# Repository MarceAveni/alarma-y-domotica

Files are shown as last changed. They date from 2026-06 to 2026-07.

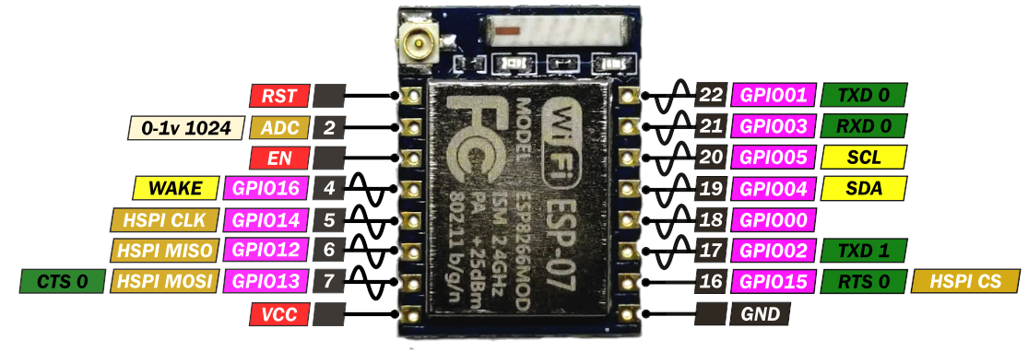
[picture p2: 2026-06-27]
Diseño y Hardware/Desarrollo de Hardware/Frente - ESP8266/Documentacion/ESP07-PinOut_solo.png

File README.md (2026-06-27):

# Alarma y Domótica del Hogar

Este repositorio unifica el código fuente de los firmwares, modelos 3D, esquemas de hardware y documentación general de los sistemas de automatización y seguridad instalados en el hogar.

## 🚀 Versión 1.0 - Versión Inicial Estable
Esta es la primera versión completada, probada y en funcionamiento del sistema integrado.

---

## 📂 Estructura del Repositorio

*   **`Control integrado - Frente/`**: Firmware para el módulo ESP8266 que controla la seguridad del frente, sensores de movimiento PIR, sirena, reflectores y luces de vereda.
*   **`Control integrado - Patio/`**: Firmware para el módulo ESP32 que controla la temperatura de la piscina (pileta), colectores térmicos solares, nivel de agua y luces de la galería/patio.
*   **`Diseño y Hardware/`**:
    *   `Modelos 3D y Planos/`: Planos CAD (.dwg) y archivos STL listos para imprimir en 3D del gabinete central, gabinete frente y soportes generales.
    *   `Desarrollo de Hardware/`: Documentación técnica (pinouts) y directorios reservados para futuras revisiones de placas.

---

## 📡 Arquitectura de Comunicaciones (MQTT)

Ambas placas están conectadas a la red WiFi local y se comunican a través de un broker MQTT público (`broker.emqx.io`).

*   **Topic de Comandos (Escuchan ambos):** `BALH142N1788/Aveni793`
    *   Ambos dispositivos procesan mensajes JSON en este canal y extraen solo las variables de control que les corresponden.
*   **Topic de Telemetría Frente (ESP8266):** `BALH142N1788/Frente`
*   **Topic de Telemetría Patio (ESP32):** `BALH142N1788/Patio`

---

## 🛠️ Herramientas de Desarrollo

*   **Firmware:** [PlatformIO](https://platformio.org/) integrado en VS Code.
*   **Carga de Firmware:** Soporta programación inalámbrica **OTA** (Over The Air) localmente en ambos módulos.
*   **Espacio de Trabajo de VS Code:** Abrir el archivo `Control ESP32 - Patio.code-workspace` en la raíz para cargar ambos proyectos de firmware simultáneamente.

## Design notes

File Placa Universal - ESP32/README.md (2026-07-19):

# Placa Universal ESP32-S3 (Motherboard / Shield)

Este directorio contiene todo el diseño de hardware, modelos 3D y firmwares unificados bajo la arquitectura de la placa universal basada en el **ESP32-S3**.

## 📂 Estructura de Directorios

*   **`Hardware/`**: Archivos de diseño electrónico y documentación.
    *   `Proyecto PCB/`: Carpeta del proyecto de diseño electrónico (Altium/KiCad) que aloja los archivos de diseño y fabricación.
    *   `Diseño/`: Documentación del diseño (requerimientos, recomendaciones y pinouts) y hojas de datos de los componentes.
*   **`Modelos 3D/`**: Diseños de gabinetes protectores y soportes impresos en 3D específicos para esta placa universal.
*   **`Firmware/`**: Proyectos PlatformIO individuales para cada nodo, compartiendo código común.
    *   `Librerias_Compartidas/`: Librerías y clases C++ comunes para WiFi, MQTT, OTA, gestión de tiempo y programaciones horarias.
    *   `Frente_S3/`: Firmware específico para el nodo del Frente (Sirena, reflectores, PIRs, etc.).
    *   `Patio_S3/`: Firmware específico para el nodo del Patio/Galería (Colectores solares, piscina, nivel de agua, etc.).
    *   `Simple_S3/`: Firmware específico para el nodo Simple (reemplazo del ESP-01 para reflectores auxiliares).

## 🛠️ Compartición de Código (PlatformIO)

Para reutilizar lógica común de red y MQTT sin duplicar código, los proyectos individuales de PlatformIO configuran la directiva `lib_extra_dirs` apuntando a `Librerias_Compartidas`.

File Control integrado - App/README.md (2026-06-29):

# Propuesta de Arquitectura y Diseño de la Aplicación Móvil
## Sistema Control Integrado - Nuestro Hogar (Alarma y Domótica)

Este documento detalla la estructura tentativa, diseño estético y mapeo de variables para la nueva aplicación móvil del sistema de domótica y seguridad del hogar. Está diseñada para ser **completa, intuitiva, escalable y con un estilo visual moderno**, adaptándose tanto a los firmwares actuales (Frente y Patio) como a futuros nodos de hardware.

---

## 1. Arquitectura de Integración y Escalabilidad

La comunicación de la aplicación móvil se realiza a través de un **Broker MQTT** (actualmente `broker.emqx.io`). La App se suscribe a los temas de estado publicados por los diferentes nodos del hogar y publica comandos en los temas correspondientes para actuar sobre el hardware.

```mermaid
graph TD
    %% Estilos de nodos
    classDef app fill:#4E73DF,stroke:#fff,stroke-width:2px,color:#fff;
    classDef broker fill:#1CC88A,stroke:#fff,stroke-width:2px,color:#fff;
    classDef nodeF fill:#36B9CC,stroke:#fff,stroke-width:2px,color:#fff;
    classDef nodeP fill:#F6C23E,stroke:#fff,stroke-width:2px,color:#fff;
    classDef nodeFut fill:#858796,stroke:#fff,stroke-width:1px,color:#fff,stroke-dasharray: 5 5;

    App[App Móvil <br>Android - Kotlin / Jetpack Compose] <--> Broker[Broker MQTT <br>broker.emqx.io]
    Broker <--> ESP_Frente[ESP8266 <br>Control Frente]
    Broker <--> ESP_Patio[ESP32 <br>Control Patio]
    Broker -.-> ESP_Futuros[ESP32 / ESP8266 <br>Nodos Futuros]

    subgraph ESP_Frente [Control Frente ESP8266-07]
        DHT11_F[DHT11 Temp & Hum]
        PIRs[Sensores PIR1 & PIR2]
        LDR_F[Fotoresistencia]
        Sirena_F[Actuador Sirena]
        Reflectores_F[Reflectores Vereda/Entrada]
        LuzVereda_F[Luz de Vereda]
        Camaras_F[Alimentación Cámaras]
    end

    subgraph ESP_Patio [Control Patio ESP32]
        DHT22_P[DHT22 Temp & Hum]
        DS18B20[DS18B20 Pileta & Colector]
        Nivel_P[Sensor de Nivel de Agua]
        LDR_P[LDR Luz Patio]
        BombaPileta[Bomba Pileta]
        BombaCisterna[Bomba Cisterna]
        BombaTanque[Bomba Tanque]
        LucesPatio[Reflectores / Luz Pileta / Galería]
        Auxiliares[Salidas Aux1 & Aux2]
    end

    class App app;
    class Broker broker;
    class ESP_Frente nodeF;
    class ESP_Patio nodeP;
    class ESP_Futuros nodeFut;
```

### Principio de Escalabilidad (Futuro Hardware)
Para asegurar que se puedan agregar sensores y actuadores en el futuro sin rediseñar la App desde cero:
1. **Estructura Temática MQTT Jerárquica**: Los nuevos nodos utilizarán la estructura `NuestroHogar/[Nombre_Nodo]/Estado` para publicar telemetría en JSON y `NuestroHogar/[Nombre_Nodo]/Comando` para recibir configuraciones.
2. **Interfaz de Carga Dinámica / Modular**: La UI de la App se construirá sobre la base de tarjetas o módulos reutilizables. Si se detecta un nuevo nodo en la red MQTT, la App podrá autogenerar una sección básica o permitir activarla desde los ajustes.

---

## 2. Mapa de Navegación: Pestañas y Sectores

Se propone una interfaz con una **barra de navegación inferior (Bottom Navigation Bar)** moderna de 5 pestañas principales. Cada una de ellas agrupa un sector lógico del hogar.

### Pestaña 1: Inicio (Dashboard)
Es la pantalla de bienvenida y control rápido. Diseñada para dar información crítica de un vistazo y permitir acciones inmediatas.
*   **Estado de Conexión**: Indicador visual arriba (MQTT Conectado/Desconectado, retardo de ping).
*   **Botón de Pánico Sirena**: Botón rojo central vibrante con efecto de brillo ("Glow") y confirmación de doble toque para encender/apagar la sirena inmediatamente en caso de emergencia.
*   **Resumen Climatológico**: Tarjeta con la temperatura y humedad exterior promedio (Frente + Patio).
*   **Resumen Pileta**: Muestra rápida de la temperatura actual de la pileta y si el sistema solar está en funcionamiento.
*   **Alertas Activas**: Banner dinámico si hay alarmas de movimiento recientes, nivel de cisterna bajo, o si alguna bomba lleva funcionando más de lo normal.

### Pestaña 2: Climatización (Pileta)
Sector especializado en el control del climatizador solar de la pileta y las bombas.
*   **Dial de Control Termostato**: Control circular interactivo y táctil para setear `tempSet` (temperatura de consigna de la pileta).
*   **Monitoreo Térmico**:
    *   `tempPileta` (Temperatura actual del agua).
    *   `tempColector` (Temperatura en colectores solares del techo).
    *   `Diferencial de Temperatura` (`tempColector - tempPileta` con indicación visual de transferencia de calor).
*   **Modo de Bomba Pileta**: Selector de tres estados (Apagado / Encendido / Automático) utilizando controles deslizantes o botones segmentados de diseño premium.
*   **Interruptor de Intercambio Solar**: Switch de activación para la lógica automática diferencial (`IntercambioST`).
*   **Diagnóstico de Bomba**:
    *   Estado real de funcionamiento (`bombaPiletaST`).
    *   Tiempo actual de encendido continuo y tiempo acumulado en el día.
    *   Alertas de seguridad (si está bloqueada por `minOffTime` o apagada por `maxOnTime`).

### Pestaña 3: Iluminación y Servicios (Domótica)
Sector dedicado al control de luces, bombas de agua y relés auxiliares.
*   **Sección Luces**: Tarjetas dinámicas con micro-animaciones (cambio de tonalidad y gradiente cuando se encienden).
    *   *Frente*: Reflectores (Apagado/Encendido/Auto), Luz de Vereda (Apagado/Encendido/Auto).
    *   *Patio*: Reflectores Patio (Apagado/Encendido/Auto), Luces Pileta (Apagado/Encendido/Auto), Luz Galería (Apagado/Encendido/Auto), Luz Galería Borde (Apagado/Encendido/Auto).
*   **Sección Agua (Pumps)**:
    *   **Nivel de Cisterna**: Gráfico de barra vertical con degradado azul que muestra si el sensor capacitivo detecta agua (`nivelAguaST`).
    *   **Bomba Cisterna**: Control segmentado (Apagado / Encendido / Auto).
    *   **Bomba Tanque**: Control segmentado (Apagado / Encendido / Auto).
*   **Sección Auxiliares**:
    *   Interruptores rápidos para `Aux1` y `Aux2`. Permite personalizar el nombre desde la interfaz (ej. "Riego", "Cascada Pileta").

### Pestaña 4: Seguridad (Alarma)
Control completo de la seguridad perimetral de la casa.
*   **Armado de Alarma**: Estado de armado general de la casa (permite integrar lógica de armado ausente/presente en el futuro).
*   **Alimentación de Cámaras**: Interruptor directo para apagar o encender (resetear) las cámaras de seguridad (`CamarasEn`).
*   **Configuración de Sirena**: Modo de Sirena general (Apagada / Automática).
*   **Estado de Sensores**:
    *   Visualización de detección en tiempo real para `PIR1` y `PIR2`.
    *   Interruptor para deshabilitar individualmente cada sensor (`PIR1En`, `PIR2En`) si alguno empieza a fallar o dar falsos positivos.
*   **Historial de Eventos (Log de Movimientos)**:
    *   Registro temporal de detecciones de movimiento.
    *   Filtro por día (con selector de fecha nativo en calendario) para auditoría de movimientos históricos.

### Pestaña 5: Configuración Avanzada (Variables)
Sector protegido para calibrar el comportamiento de los algoritmos de las placas ESP.
*   **Parámetros de Pileta**:
    *   Entradas numéricas para delta de encendido (`tempDif_on`) y delta de apagado (`tempDif_off`).
    *   Ajuste de tiempos de protección de bomba en minutos (`minOnTime`, `minOffTime`, `maxOnTime`).
*   **Ajustes de Luz y Noche**:
    *   Ajuste del umbral `ValorNoche` del conversor analógico-digital (ADC) para clasificar cuándo es de noche.
    *   Ajuste de histéresis (`histeresisLuz`).
*   **Configuración del Sistema**:
    *   Intervalo de telemetría en segundos (`intervalData`).
    *   Parámetros del Broker MQTT (Host, Port, User, Pass).
    *   **Diagnóstico de Hardware**: Mapeo de WiFi (señal RSSI en dBm de Frente y Patio), direcciones IP asignadas, tiempo de actividad (uptime) y opción de iniciar actualización de firmware OTA de forma inalámbrica.

---

## 3. Guía de Diseño Estético y Experiencia de Usuario (UX/UI)

Para lograr una interfaz premium, intuitiva y moderna (diseño "WOW"), se propone seguir las siguientes pautas visuales:

1.  **Gama de Colores e Identidad Visual**:
    *   **Tema Oscuro por Defecto**: Fondo en gris muy oscuro (`#121214` o `#0F0F12`) con tarjetas en gris grafito (`#1E1E24`) y bordes muy sutiles (`#2D2D35`). Esto ahorra batería (pantallas OLED/AMOLED) y da un aspecto tecnológico de alta gama.
    *   **Acentos de Color por Categoría**:
        *   *Domótica/Climatización*: Azul eléctrico (`#00D4FF` o `#007BFF`) y turquesa.
        *   *Iluminación*: Amarillo cálido / Ámbar (`#FFB300` o `#FF8F00`) simulando la calidez de los filamentos.
        *   *Seguridad*: Rojo vivo (`#FF3B30`) y Naranja (`#FF9500`).
        *   *Estado OK*: Verde esmeralda (`#34C759`).
2.  **Morfología (Glassmorphism)**:
    *   Uso de tarjetas translúcidas con desenfoque de fondo ("background blur") y bordes degradados muy finos que simulan vidrio sobre un fondo con sutiles orbes de color desenfocados.
    *   Esquinas redondeadas suaves (entre 12dp y 16dp) para una estética moderna y amigable.
3.  **Controles de Interacción e Iconografía**:
    *   Uso de iconos vectoriales limpios y de trazo fino (estilo Outlined de Material Design 3).
    *   Diales táctiles circulares y fluidos para variables analógicas (temperatura setpoint).
    *   Feedback háptico (vibración suave) al interactuar con interruptores y botones clave (como el botón de pánico).

---

## 4. Estructura de Datos y Comunicación MQTT

A continuación, se detalla la matriz de comunicación de la aplicación con los dos sistemas de hardware actuales:

### Canalización de Mensajería: Control Frente (ESP8266)

| Variable / Control | Dirección | Tema (Topic) MQTT | Formato de Payload / Valores |
| :--- | :--- | :--- | :--- |
| **Temperatura Frente** | Recibe de ESP | `Ambiente/Temp` | Texto: `"Temperatura: [Valor] "` (ej. `"Temperatura: 25 "`) |
| **Humedad Frente** | Recibe de ESP | `Ambiente/Hum` | Texto: `"Humedad: [Valor] "` (ej. `"Humedad: 60 "`) |
| **Luz Frente** | Recibe de ESP | `Ambiente/Luz` | Texto: `"Es de [día/noche]: [Valor]"` |
| **Sensor PIR 1** | Recibe de ESP | `Movimiento/PIR1` | Texto: `"Movimiento Detectado!!!"` |
| **Sensor PIR 2** | Recibe de ESP | `Movimiento/PIR2` | Texto: `"Movimiento Detectado!!!"` |
| **Contador de Movimientos**| Recibe de ESP | `Movimiento/PIRc` | Texto: `"Cant. de movimientos detectados: [Valor] "` |
| **Reflectores Frente** | Envía a ESP | `Iluminacion/Reflectores`| Entero: `0` (Apagado), `1` (Encendido) *(Se propone expandir a `2` Auto)* |
| **Luz Vereda** | Envía a ESP | `Iluminacion/Vereda` | Entero: `0` (Apagado), `1` (Encendido) *(Se propone expandir a `2` Auto)* |
| **Sirena** | Envía a ESP | `Alarma/Sirena` | Entero: `0` (Apagado), `1` (Encendido) |
| **Cámaras** | Envía a ESP | `Alarma/Camaras` | Entero: `0` (Apagado), `1` (Encendido) |

### Canalización de Mensajería: Control Patio (ESP32)

El ESP32 del patio utiliza un formato JSON estructurado, lo que optimiza el tráfico de datos y simplifica la expansión de variables.

*   **Tema de Publicación (Telemetría)**: `BALH142N1788/Patio`
*   **Tema de Suscripción (Comandos)**: `BALH142N1788/Aveni793`

#### Estructura del JSON de Telemetría (Publicado por ESP32):
```json
{
  "tempPileta": 24.5,
  "tempColector": 28.2,
  "bombaPiletaST": false,
  "bombaPiletaConf": 2,
  "tempSet": 30.0,
  "tempDif_on": 5.0,
  "tempDif_off": 2.0,
  "minOnTime": 60000,
  "minOffTime": 300000,
  "maxOnTime": 900000,
  "bombaCisternaST": false,
  "bombaCisternaConf": 2,
  "bombaTanqueST": false,
  "bombaTanqueConf": 2,
  "reflectoresST": false,
  "reflectoresConf": 2,
  "luzPiletaST": false,
  "luzPiletaConf": 2,
  "luzGaleriaST": false,
  "luzGaleriaConf": 2,
  "luzGaleriaBordeST": false,
  "luzGaleriaBordeConf": 2,
  "luzAmbiente": 450,
  "nivelAgua": true,
  "tempTecho": 22.1,
  "humTecho": 55.0,
  "IntercambioST": true,
  "tempPiletaCrudo": 24.53,
  "tempColectorCrudo": 28.18
}
```

#### Estructura del JSON de Comandos (Enviado por la App):
La aplicación puede enviar un JSON parcial conteniendo únicamente las llaves que desea modificar.
```json
{
  "tempSet": 29.5,
  "bombaPiletaConf": 2,
  "reflectoresConf": 1,
  "luzPiletaConf": 0
}
```

---

## 5. Planificación del Desarrollo de la App

Para la construcción de la App se utilizarán las tecnologías nativas que ya posees configuradas y listas para usar:
*   **IDE**: Visual Studio Code o Android Studio Koala (2024.1.1 Patch 1)
*   **Lenguaje**: Kotlin con Jetpack Compose para una UI reactiva y moderna.
*   **Librerías Clave**:
    *   `org.eclipse.paho:org.eclipse.paho.client.mqttv3` o biblioteca Kotlin-friendly para la gestión de conexión MQTT en segundo plano con persistencia.
    *   `kotlinx.serialization` o `Gson` para serialización/deserialización ágil de payloads JSON.
    *   `Room` (Base de datos SQLite local) para almacenar el historial de alarmas y logs de movimiento sin depender siempre del broker.
    *   `Retrofit` o llamadas de red básicas (si a futuro se añade una API Rest).

El proyecto se ubicará en la nueva carpeta `Control integrado - App` dentro de la estructura raíz para mantener el orden de tus repositorios.

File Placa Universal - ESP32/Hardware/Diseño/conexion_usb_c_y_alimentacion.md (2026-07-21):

# Guía de Conexión USB-C y Protección de Alimentación Dual

Este documento explica cómo implementar el puerto USB-C nativo para el ESP32-S3 en Altium y cómo diseñar el circuito de protección para que la placa pueda alimentarse simultáneamente desde el USB-C (5V) y desde la fuente principal (12V reducidos a 5V por el Buck) sin dañar la computadora ni el regulador.

---

## 1. Conector USB-C: Pines necesarios y conexiones

Para USB 2.0 (como el del ESP32-S3), **no necesitas usar un conector de 24 pines** (que es muy difícil de soldar y rutear). Te recomiendo usar un **conector USB-C de 16 pines** (a veces llamado de 12 pines porque agrupa las masas y alimentaciones).

### Mapeo de Pines del Conector USB-C (16 pines):

```text
  A1/B12 (GND)  A4/B9 (VBUS)  A5 (CC1)   A6 (D+)    A7 (D-)   B5 (CC2)
     [|]           [|]          [|]        [|]        [|]        [|]
      |             |            |          |          |          |
     GND          VBUS         5.1k       22 Ohm     22 Ohm     5.1k
    Placa        (5V USB)        |          |          |          |
                                GND      GPIO 20    GPIO 19      GND
                                         (USB_D+)   (USB_D-)
```

1.  **Masa (GND)**: Conecta todos los pines `GND` (A1, A12, B1, B12) al plano de masa digital (`GND_DF`) de la placa.
2.  **Alimentación (VBUS)**: Conecta todos los pines de alimentación `VBUS` (A4, A9, B4, B9) entre sí. Esta línea transporta los 5V provenientes del puerto USB de la PC.
3.  **Líneas de Datos (D+ y D-)**:
    *   **D+ (A6, B6)**: Conéctalos juntos y llévalos al pin **GPIO 20** (`USB_D+`) del ESP32-S3 a través de una resistencia de **22 Ohm** en serie.
    *   **D- (A7, B7)**: Conéctalos juntos y llévalos al pin **GPIO 19** (`USB_D-`) del ESP32-S3 a través de una resistencia de **22 Ohm** en serie.
    *   *Nota*: Estas resistencias de 22 Ohm sirven para adaptar la impedancia de la línea a 90 Ohm diferenciales.
4.  **Configuración de Puerto (CC1 y CC2)**:
    *   Conecta una resistencia de **5.1 kΩ (precisión 1%)** desde el pin `CC1` (A5) a `GND`.
    *   Conecta otra resistencia de **5.1 kΩ (precisión 1%)** desde el pin `CC2` (B5) a `GND`.
    *   **¡ADVERTENCIA!**: Deben ser **dos resistencias independientes**. No unas los pines CC1 y CC2 para usar una sola resistencia, ya que esto evitaría que ciertos cables modernos de doble conector USB-C (C-to-C) entreguen energía.

---

## 2. Circuitos de Protección de Alimentación Dual

Queremos evitar el "retorno" de corriente (backfeeding). Si conectas el cable USB de la computadora y al mismo tiempo enciendes la fuente de 12V de la placa, el regulador Buck de 5V y el puerto USB de la PC competirán. Esto puede quemar el puerto de la PC o el regulador.

Aquí tienes dos opciones para resolver esto en tu esquemático:

### OPCIÓN 1: La solución simple (Doble Diodo Schottky)
Es la opción más barata y sencilla. Consiste en colocar un diodo en serie con cada fuente de alimentación apuntando hacia la línea interna de `+5V_SYS` de la placa.

```text
VBUS (USB 5V) ------->|-[ Diodo D1: SS14 ]---------+-------> +5V_SYS (Alimentación interna)
                                                   |
5V_BUCK ------------->|-[ Diodo D2: SS14 ]---------+
```

*   **Funcionamiento**: Los diodos actúan como válvulas de retención de una sola vía. Si `5V_BUCK` es mayor que `VBUS`, D2 conduce y D1 se bloquea, impidiendo que la corriente del Buck vaya hacia la computadora. Si el Buck está apagado, D1 conduce y el USB alimenta la placa.
*   **Componente recomendado**: Diodo Schottky **SS14** o **B130** (encapsulado SMA o SOD-123, soportan 1A/30V y tienen muy baja caída de tensión).
*   **Desventaja**: Los diodos Schottky tienen una caída de tensión de unos **0.3V a 0.4V**. Por ende, la línea `+5V_SYS` tendrá realmente unos 4.6V a 4.7V. Esto es suficiente para el regulador LDO de 3.3V (que alimenta el ESP32-S3), pero puede no ser ideal si tienes sensores o relés que requieran exactamente 5.0V.

---

### OPCIÓN 2: La solución profesional (Selector MOSFET automático)
Es la topología que usan las placas oficiales de Arduino. Evita la caída de tensión del diodo en la línea USB usando un MOSFET de canal P como interruptor de estado sólido.

```text
VBUS (USB 5V) -----[ Source  MOSFET Canal-P (AO3401)  Drain ]-----+---> +5V_SYS
                                     |                             |
                                     Gate                          |
                                     |                             |
5V_BUCK -----------------------------+--->|-[ Diodo D2: SS14 ]-----+
                                     |
                                 [ R: 10k ]
                                     |
                                    GND
```

*   **Funcionamiento**:
    *   **Caso 1 (Solo USB conectado)**: `5V_BUCK` está en 0V. La compuerta (Gate) del MOSFET de canal P es llevada a GND (0V) por la resistencia de pull-down de 10k. Esto enciende el MOSFET por completo, dejando pasar los 5V de `VBUS` a `+5V_SYS` con **cero caída de tensión** (gracias a la bajísima resistencia $R_{ds(on)}$ del MOSFET).
    *   **Caso 2 (Alimentación externa de 12V encendida)**: El regulador Buck entrega 5V a la línea `5V_BUCK`. Esto pone la compuerta (Gate) del MOSFET a 5V. Al estar la Gate a la misma tensión que el Source (`VBUS`), el MOSFET **se apaga por completo**, aislando el puerto USB de la computadora. La placa pasa a alimentarse del Buck a través del diodo D2.
*   **Componentes recomendados**:
    *   MOSFET Canal P: **AO3401** (SMD encapsulado SOT-23, muy común y barato).
    *   Diodo D2: **SS14** o **B130**.

---

## 3. Protección ESD en Líneas USB (Integrado USBLC6-2SC6)

Cuando alguien enchufa o desenchufa un cable USB-C, se pueden generar descargas de electricidad estática (ESD) de miles de voltios. El integrado **USBLC6-2SC6** (de *STMicroelectronics*) es un chip diminuto en encapsulado **SOT-23-6L** de 6 pines, diseñado específicamente para absorber estas descargas en líneas USB 2.0 sin alterar la señal de datos.

### Mapeo de Pines del USBLC6-2SC6 (SOT-23-6L):

```text
                  +---------------+
        D+ (USB) -| 1 I/O1   6 I/O1|- D+ (hacia ESP32)
             GND -| 2 GND    5 VBUS|- VBUS (5V USB)
        D- (USB) -| 3 I/O2   4 I/O2|- D- (hacia ESP32)
                  +---------------+
```

### Cómo conectarlo en el Esquemático:
1.  **Pin 1 y Pin 6 (I/O 1 - Canal D+)**:
    *   Pin 1 va conectado hacia el terminal **D+** del conector USB-C.
    *   Pin 6 va conectado hacia la resistencia de 22 Ohm que se dirige al pin **GPIO 20** (`USB_D+`) del ESP32-S3.
2.  **Pin 3 y Pin 4 (I/O 2 - Canal D-)**:
    *   Pin 3 va conectado hacia el terminal **D-** del conector USB-C.
    *   Pin 4 va conectado hacia la resistencia de 22 Ohm que se dirige al pin **GPIO 19** (`USB_D-`) del ESP32-S3.
3.  **Pin 2 (GND)**: Conectado a la masa digital de la placa (`GND_DF`).
4.  **Pin 5 (VBUS)**: Conectado a la línea de alimentación de 5V del conector USB-C (`VBUS`). Además de proteger los datos, recorta picos de tensión en la alimentación de 5V.

### Regla de Ruteo (Flow-Through):
Este integrado está diseñado con una disposición de pines tipo **Flow-Through** (atravesar): la pista de datos `D+` entra por el Pin 1 y sale directamente por el Pin 6 que está enfrentado. Esto te permite colocar el componente en el PCB **directamente sobre el camino de las pistas de datos**, sin crear bifurcaciones ("stubs") ni alterar la impedancia diferencial.

*   **Ubicación en el PCB**: Debe colocarse físicamente **lo más cerca posible del conector USB-C**, antes de cualquier otro componente o resistencia de la línea de datos.

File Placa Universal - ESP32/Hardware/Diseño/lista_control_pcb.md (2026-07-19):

# Lista de Control (Checklist) para el Diseño del PCB

Usa esta lista en Altium para verificar cada circuito y evitar errores de hardware clásicos antes de mandar a fabricar las placas. Puedes marcar las casillas colocando una `x` entre los corchetes (ej: `[x]`).

---

## 1. Módulo ESP32-S3 y Configuración de Arranque
- [ ] **Huella de Altium**: ¿Se utilizó el footprint para el `ESP32-S3-WROOM-1` (largo, 25.5 mm)? *Esto permitirá soldar tanto la versión con antena integrada como la versión -1U de antena externa.*
- [ ] **Exclusión de Cobre (Antena Keepout)**: ¿El área de 6.0 mm superiores del módulo (antena) sobresale del borde de la placa, o está libre de planos de masa y pistas en todas las capas del PCB?
- [ ] **Desacoplamiento de alimentación**: ¿Se colocaron un capacitor electrolítico/tántalo de **22 µF** en paralelo con uno cerámico de **0.1 µF (100nF)** pegados físicamente a los pines `3V3` y `GND` del módulo?
- [ ] **Circuito de Reset (EN)**: ¿Tiene una resistencia de **10 kΩ** a 3.3V y un capacitor de **1 µF** a GND? ¿Se colocó el pulsador en paralelo con el capacitor?
- [ ] **Circuito de Boot (GPIO 0)**: ¿Tiene su pull-up de **10 kΩ** a 3.3V y un pulsador a GND pasando por una resistencia protectora de **470 Ohm**?
- [ ] **Pines de Arranque (Strapping Pins)**: ¿Están los pines `GPIO 45` y `GPIO 46` libres de pull-ups externas que puedan impedir que el micro arranque?
- [ ] **Acceso a Programación USB Nativo**: 
    - [ ] ¿Se conectaron resistencias en serie de **22 Ohm** (o 0 Ohm) en las líneas `D-` (GPIO 19) y `D+` (GPIO 20) del USB-C?
    - [ ] ¿Se agregaron resistencias de **5.1 kΩ** independientes conectadas de `CC1` y `CC2` del conector USB-C hacia `GND`?
    - [ ] ¿Se agregó el integrado de protección ESD en las líneas del USB-C?

---

## 2. Bloque de Alimentación
- [ ] **Protección de Entrada 12V**: ¿Tiene un fusible reseteable **PTC (2A/3A)** y diodos TVS o Varistores para proteger contra sobretensiones transitorias?
- [ ] **Protección contra Inversión**: ¿Se incluyó un diodo Schottky o un transistor MOSFET de canal P para proteger el circuito ante conexión de fuente invertida?
- [ ] **Regulador Buck (12V -> 5V)**: ¿Los capacitores de filtrado y la bobina blindada están ruteados con pistas cortas y anchas de acuerdo al datasheet del integrado regulador conmutado?
- [ ] **Regulador LDO (5V -> 3.3V)**: ¿Tiene capacitores cerámicos de tántalo o bajo ESR a la entrada y a la salida para evitar oscilaciones?

---

## 3. Entradas Digitales (16 Canales)
- [ ] **Aislamiento Galvánico (Optoacopladores PC817)**: ¿Se colocó optoacoplador por cada canal para separar eléctricamente los bornes exteriores del expansor MCP23017?
- [ ] **Resistencias limitadoras**: ¿Se calcularon las resistencias en serie del LED del optoacoplador para la tensión de entrada esperada (ej. **1k a 1.5k Ohm** para entradas de 12V)?
- [ ] **Diodo antiparalelo**: ¿Tiene cada entrada un diodo (ej. *1N4148*) en antiparalelo con el LED del optoacoplador para protegerlo contra polarizaciones inversas accidentales?
- [ ] **Filtro de Ruido y Pull-ups**: ¿Tiene cada entrada del MCP23017 una resistencia de pull-up a 3.3V (ej. **10k Ohm**) y un capacitor de filtrado a GND (ej. **10nF**) para evitar falsos disparos por hardware?

---

## 4. Salidas de Control
- [ ] **Salidas para SSR Externos (6 Canales)**: 
    - [ ] ¿Las salidas lógicas pasan por un array Darlington **ULN2803/ULN2003** para no cargar de corriente al MCP23017?
    - [ ] ¿Los conectores de salida disponen de un pin con alimentación de **5V** para polarizar los módulos externos y un pin de masa **GND**?
- [ ] **Salidas MOSFET DC en Placa (4 Canales)**:
    - [ ] ¿Se utilizaron MOSFETs Logic-Level (ej. *AOD4184* o *IRLZ44N*) que saturen completamente a 5V/12V?
    - [ ] ¿Se colocó una resistencia de compuerta (*Gate*) de **100 Ohm** en serie?
    - [ ] ¿Tiene cada compuerta una resistencia de pull-down de **10 kΩ** a GND para mantener las salidas inactivas durante el arranque del micro?
    - [ ] ¿Se colocaron diodos Schottky flyback (ej. *SS34*) en paralelo con los bornes de salida para proteger los transistores ante cargas inductivas (sirenas)?

---

## 5. Sensores e Interfaces de Comunicación
- [ ] **Sensores Ultrasonido (JSN-SR04T)**:
    - [ ] ¿Se diseñó la señal de Trigger común hacia los 4 conectores?
    - [ ] ¿Tiene cada una de las 4 líneas de Echo un divisor de tensión resistivo (ej. **1k Ohm** en serie y **2k Ohm** a GND) para bajar la señal del pulso de 5V a 3.3V?
- [ ] **Bus I2C (MCP23017 y pantalla)**: ¿Tiene resistencias de pull-up externas de **4.7 kΩ** en las líneas SDA y SCL a 3.3V?
- [ ] **Bus 1-Wire (Sensores DS18B20)**: ¿Tiene su terminal de conexión con resistencia de pull-up de **4.7 kΩ** (o **2.2 kΩ** para cables largos) conectada a 3.3V?
- [ ] **Protección ESD de Sensores**: ¿Se colocaron arrays de diodos TVS (*USBLC6-2*) en las borneras externas de I2C, 1-Wire y analógicas expuestas al tacto y cableado exterior?
- [ ] **RS485 Aislado**: ¿El transceptor RS485 está alimentado mediante una fuente aislada (ej. *B0505S*) y aislado galvánicamente del microcontrolador?
- [ ] **RS485 Resistencia de Terminación**: ¿Tiene una resistencia de **120 Ohm** en paralelo con las líneas A-B con posibilidad de activarse/desactivarse mediante un jumper físico?
- [ ] **Ethernet (W5500)**: ¿Tiene las resistencias de pull-up recomendadas en las señales del bus SPI y desacoplamiento en su línea de alimentación?

---

## 6. Layout y Reteado
- [ ] **Zona Analógica del ADC**: ¿Las pistas analógicas (GPIOs 1-4) están lo más cortas posibles y alejadas de líneas conmutadas de alta frecuencia?
- [ ] **Retorno de Corrientes (Planos de Masa)**: ¿El plano de masa digital (`GND_DF`) está separado del plano de potencia (`GND_PWR`) y unidos en un único punto estrella de la fuente?
- [ ] **Ancho de pista de alimentación**: ¿Las pistas de 12V y 5V que alimentan relés y MOSFETs tienen un ancho adecuado (mínimo 2mm o polígonos)?

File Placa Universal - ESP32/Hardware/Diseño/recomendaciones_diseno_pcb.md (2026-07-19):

# Recomendaciones de Diseño de PCB y Esquemas - Placa Universal ESP32-S3

Este documento proporciona pautas de diseño electrónico y de circuito impreso (PCB) para la Placa Universal. Su objetivo es garantizar la estabilidad del sistema, mitigar el ruido electromagnético de relés y sirenas, y proteger el ESP32-S3 de transitorios en cables largos.

Al optar por **conectar módulos SSR de manera externa (Opción B)**, el PCB principal queda libre de alta tensión (220VAC), lo que reduce drásticamente el tamaño físico de la placa, abarata los costos de fabricación y elimina el ruido de conmutación de corriente alterna cerca del microcontrolador.

---

## 1. Topología del PCB y Zonas de Aislamiento

Aunque la placa ahora es 100% de baja tensión continua (DC), sigue siendo fundamental separar las líneas de alta corriente (12V para sirenas y actuadores) de las señales de control de alta velocidad (ESP32-S3, buses I2C/SPI).

```text
+-------------------------------------------------------------------+
|               ZONA DE CONTROL (Baja Potencia)                     |
|  [ESP32-S3]     [MCP23017]     [Regulador LDO 3.3V]    [I2C/SPI]  |
+-------------------------------------------------------------------+
|               ZONA DE AISLAMIENTO (Barrera)                       |
|  [Optoacopladores PC817]              [Drivers ULN2803/MOSFETs]   |
+-------------------------------------------------------------------+
|               ZONA DE POTENCIA DC y CONECTORES                    |
|  [Mosfets Sirena/DC]   [Conectores SSR/Sensores]   [Regulador Buck]|
+-------------------------------------------------------------------+
```

### Reglas de Layout (Ruteo):
1.  **Planos de Masa Separados**: 
    *   `GND_DF` (Masa digital de control, conectada al ESP32-S3 y expansores).
    *   `GND_PWR` (Masa de potencia de 12V para sirenas, electroválvulas y regulador Buck).
    *   Ambos planos deben unirse en **un solo punto** (Star Ground) cerca del capacitor de entrada de 12V, asegurando que las corrientes de retorno de la sirena no fluyan por debajo del ESP32-S3.
2.  **Ancho de Pistas de Potencia**:
    *   Pistas de masa y alimentación de 12V (hacia los MOSFETs): Mínimo 2 mm (o usar polígonos de cobre) para soportar de forma segura corrientes pico de sirena de hasta 5A.

---

## 2. Circuitos Propuestos por Sección

### A. Alimentación y Regulación
*   **Regulador Buck (12V -> 5V)**: Usar un regulador de alta eficiencia como el **MP2315** o **AP63205** para alimentar las entradas de los módulos SSR externos, sensores ultrasónicos y la línea del regulador LDO de 3.3V.
*   **Regulador LDO (5V -> 3.3V)**: Usar un chip lineal robusto como el **AP2112K-3.3** o **AMS1117-3.3** en SOT-223 para el ESP32-S3 y sensores locales de 3.3V.

### B. Entradas Digitales Optoacopladas (16 Canales)
Para conmutar las entradas del MCP23017 de manera segura usando 12V o 5V externos:

```text
(Entrada exterior +12V) ----[ R1: 1k Ohm ]----+-----------------+
                                              |                 |
                                           [ Diodo ]        [ Led Opto ] (PC817)
                                          (Inverso/1N4148)      |
(Retorno Exterior GND) -----------------------+-----------------+

----------------------- Aislamiento Físico -----------------------

(VCC 3.3V) ----[ R2: 10k Ohm ]----+----> Pin Entrada MCP23017
                                  |
                           [ Colector Opto ] (PC817)
                                  |
                           [ Emisor Opto ]
                                  |
(GND Digital) --------------------+----+----> Capacitor Filtro (10nF)
```
*   *Función del Diodo 1N4148*: Protege el LED del optoacoplador en caso de conexión inversa accidental de los cables del sensor.
*   *Capacitor de 10nF*: Junto con R2, forma un filtro paso bajo de hardware que elimina rebotes de alta frecuencia y ruidos inducidos antes de llegar al MCP23017.

### C. Conexiones y Activación de SSRs Externos (6 Canales)
Al no integrar los relés de alterna en la PCB, dejamos borneras o pines de conexión que transportan la alimentación y la señal lógica de control. 

#### Métodos de Activación según Tipo de Módulo:
1.  **Módulos Comerciales SSR (Activos en Bajo / Active-Low)**:
    *   Muchos módulos comerciales de 4 canales G3MB-202P se activan drenando corriente a masa (GND).
    *   **Propuesta**: Conectar las 6 salidas del MCP23017 a un chip driver Darlington **ULN2803** (o **ULN2003**). Las salidas del ULN actúan como interruptores a masa (sink) capaces de manejar hasta 500mA por canal sin sobrecargar el expansor I2C.
2.  **Módulos Comerciales SSR (Activos en Alto / Active-High)**:
    *   Si el módulo externo requiere una señal de 5V activa para encender, las salidas del MCP23017 (que funcionan a 3.3V) se pueden pasar por un desplazador de nivel (ej. chip **74HCT244** o transistores individuales).

#### Diseño del Conector (Ejemplo de Bornera / Pin Header):
*   **Conector 1 (Módulo 4 Canales SSR)**: Exponer un conector con 6 pines: `[ VCC 5V, GND, In1, In2, In3, In4 ]`.
*   **Conector 2 y 3 (SSRs de potencia individuales)**: Dos conectores de 2 pines (o borneras de paso 3.81mm): `[ VCC 5V/12V, Señal Control ]`.

### D. Salidas MOSFET de Potencia DC en Placa (4 Canales)
Para controlar sirenas de 12V y reflectores DC de alta potencia:
*   Usar MOSFETs de canal N con nivel lógico de compuerta (Logic-Level Gate), como el **IRLZ44N** (TH) o **AOD4184** (SMD).
*   **Circuito de disparo**:
    *   Resistencia en serie con la compuerta (Gate): **100 Ohm** para limitar la corriente transitoria de carga de la compuerta.
    *   Resistencia de Pull-Down en la compuerta: **10k Ohm** a GND para asegurar que el MOSFET permanezca apagado durante el arranque del microcontrolador.
    *   **Diodo Schottky flyback (paralelo a la bornera de salida)**: Indispensable (ej. *SS34* o *1N5822*) para derivar el pico inductivo inverso al apagar sirenas o solenoides.

---

## 3. Interfaces de Comunicación y Sensores

### A. Bus I2C y 1-Wire (Protección contra descargas)
Los cables que van hacia sensores externos (como sensores de temperatura DS18B20 o displays lejanos) pueden actuar como antenas y acumular electricidad estática.
*   Colocar arreglos de diodos de protección ESD tipo **USBLC6-2SC6** en las líneas de SDA, SCL y la línea de datos de 1-Wire. Esto derivará cualquier descarga estática a tierra antes de que alcance el ESP32-S3.
*   **Resistencias de Pull-Up**:
    *   I2C: Resistencias de **4.7k Ohm** a 3.3V.
    *   1-Wire: Resistencia de **4.7k Ohm** (o **2.2k Ohm** si los cables de los sensores de temperatura son muy largos) a 3.3V.

### B. RS485 Aislado Galvánicamente
Para una comunicación RS485 robusta e industrial:
*   Usar un transceptor RS485 aislado como el **ADM2483** (o un transceptor clásico **MAX485** acoplado con optoacopladores rápidos de alta velocidad y un convertidor DC-DC aislado de 5V a 5V como el **B0505S-1W**).
*   Esto asegura que fallas eléctricas o diferencias de potencial de tierra entre la placa principal y los módulos remotos RS485 no quemen el circuito.

### C. Sensores por Ultrasonido (4 Canales - JSN-SR04T)
*   **Análisis de Interferencia Acústica (Crosstalk)**:
    Al disparar los 4 sensores simultáneamente usando un Trigger común, si están instalados en recipientes separados (ej. Tanque de agua de reserva, cisterna bajo tierra, piscina y depósito de agua de riego), **no habrá interferencia**. 
    *   *Si existiese riesgo de interferencia*, una alternativa elegante de hardware es pasar la señal de Trigger a través de una compuerta lógica demultiplexora (ej. **74HC138** o **74HC125**) controlada por el MCP23017 para activar selectivamente el Trigger del sensor que se desea medir en ese instante, usando un único pin de Trigger nativo de alta precisión del ESP32-S3.
*   **Adaptación de Voltaje**: El JSN-SR04T funciona a **5V**. La señal de Echo que retorna del sensor es de 5V. El ESP32-S3 solo tolera **3.3V**.
    *   *Solución*: Colocar un divisor de tensión resistivo (ej. **1k Ohm** en serie y **2k Ohm** a GND) en cada línea de Echo antes de entrar al GPIO del ESP32-S3, reduciendo la señal de 5V a 3.3V seguros.

---

## 4. Conectores Recomendados
*   Para salidas de potencia DC (MOSFETs, Alimentación): Borneras de tornillo de **paso 5.08 mm**.
*   Para las salidas de control SSR, entradas analógicas y sensores (1-Wire, Ultrasonido): Borneras de tornillo de **paso 3.81 mm** o conectores tipo JST XH2.54 para conexiones rápidas de sensores.
*   Para expansión/I2C/SPI: Conectores tipo pin header macho/hembra de **paso 2.54 mm** estándar.

---

## 5. Componentes de Soporte Mínimos para el ESP32-S3-WROOM-1

Para garantizar que el módulo inicie correctamente, sea fácil de programar y funcione de forma segura ante ruidos y descargas, debes incluir los siguientes componentes periféricos asociados al módulo en tu esquema de Altium:

### A. Circuito de Alimentación y Desacoplamiento (Pin 3V3 y GND)
El ESP32-S3 consume picos de corriente elevados (hasta 350-500mA) durante la transmisión de WiFi.
*   **Capacitor de desacoplamiento de alta capacidad**: Coloca un capacitor de tántalo o electrolítico SMD de **22 µF** (o 10µF) en paralelo con un capacitor cerámico de **0.1 µF (100nF)**.
*   *Ubicación*: Deben colocarse **lo más cerca posible** del pin `3V3` (Pin 2) y el pin `GND` (Pin 1) del módulo, con pistas anchas de alimentación.

### B. Circuito de Reset / Habilitación (Pin EN - Pin 3)
Para asegurar que el microcontrolador inicie de forma limpia una vez que la tensión de 3.3V se ha estabilizado:
*   **Resistencia de Pull-Up**: Resistencia de **10 kΩ** conectada a 3.3V.
*   **Capacitor de retardo**: Capacitor de **1 µF** conectado entre el pin `EN` y `GND`. Esto crea un retardo RC de inicio (aprox. 10 ms).
*   **Pulsador de Reset**: Puedes añadir un pulsador táctil en paralelo con el capacitor de 1µF para permitir un reinicio manual de la placa.

### C. Circuito de Programación por USB Nativo (Pines GPIO 19 y 20)
Dado que usaremos la programación nativa del ESP32-S3 mediante USB:
*   **Resistencias de protección en serie**: Conecta el pin `GPIO 19` (D-) y `GPIO 20` (D+) a las líneas de datos correspondientes del conector USB-C usando resistencias de **0 Ohm** o **22 Ohm** en serie (ej. encapsulado 0603). Sirven como fusibles de protección y para adaptación de impedancia de las pistas de alta velocidad.
*   **Resistencias del conector USB-C (CC1 y CC2)**: Es obligatorio colocar dos resistencias de **5.1 kΩ** conectadas individualmente desde los pines `CC1` y `CC2` del conector USB-C a `GND`. Sin estas resistencias, los cargadores modernos USB-C y los puertos de las notebooks no detectarán la placa y no le suministrarán energía (5V).
*   **Protección ESD**: Coloca un array de diodos de protección TVS como el **USBLC6-2SC6** en las líneas de datos `D+` y `D-` del USB-C.

### D. Circuito del Botón de Boot (GPIO 0 - Pin 27)
Aunque el USB nativo usualmente puede forzar el modo de programación automáticamente por software (mediante señales DTR/RTS virtuales), es altamente recomendable colocar un método físico de respaldo:
*   Coloca una resistencia de **10 kΩ** de pull-up conectada a 3.3V (aunque el chip tiene pull-up interna, asegura estabilidad ante ruido).
*   Coloca un pulsador táctil que conecte `GPIO 0` a `GND` a través de una resistencia pequeña de protección (ej. **470 Ohm**). Si mantienes presionado este botón al encender o resetear la placa, entrará obligatoriamente en modo de flasheo por hardware.

### E. Regla de Ruteo de la Antena (Keepout en Altium)
Si usas el modelo con antena de pista integrada (`ESP32-S3-WROOM-1`):
*   El módulo debe colocarse de manera que **la antena sobresalga del borde de la placa principal (overhang)**, o bien debes declarar una zona de **Keepout (exclusión de cobre)** en todas las capas del PCB directamente debajo y alrededor del área de la antena (los 6.0 mm superiores del módulo). No coloques planos de tierra, pistas de señales ni componentes en esta área, de lo contrario degradarás severamente el alcance de la radio.

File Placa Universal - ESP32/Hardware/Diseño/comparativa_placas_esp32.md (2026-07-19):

# Comparativa de Módulos ESP32 - Placa Universal

Este documento evalúa los diferentes modelos de microcontroladores de la familia ESP32 para determinar cuál es la opción más idónea para nuestra Placa Universal, considerando:
1.  **Capacidades técnicas** (pines libres, USB, ADC).
2.  **Disponibilidad local en Argentina**.
3.  **Costos relativos** (tanto en formato Placa de Desarrollo/DevKit como en Módulo de montaje superficial).
4.  **Complejidad de diseño e integración**.

---

## 1. Tabla Comparativa de Modelos

| Característica | ESP32 Clásico (WROOM-32D/U/E) | ESP32-S3 (WROOM-1/2) | ESP32-C3 (MINI-1/WROOM-02) |
| :--- | :---: | :---: | :---: |
| **Arquitectura** | Xtensa LX6 Dual-Core 32-bit | Xtensa LX7 Dual-Core 32-bit | RISC-V Single-Core 32-bit |
| **Frecuencia Máx.** | 240 MHz | 240 MHz | 160 MHz |
| **SRAM Interna** | 320 KB | 512 KB | 400 KB |
| **GPIOs Físicos** | 38 | 45 | 22 |
| **GPIOs Libres en DevKit**| ~26 a 28 | ~30 a 34 | ~15 |
| **USB Nativo (CDC/OTG)** | ❌ No (Requiere CH340/CP2102) |  Sí (Soporta Flash y JTAG) |  Sí (Soporta CDC de programación) |
| **Bluetooth** | v4.2 BR/EDR y BLE | v5.0 BLE (Mesh) | v5.0 BLE |
| **Pines Input-Only (GPI)**| 4 pines (GPIO 34-39, sin pull-ups) | ❌ Ninguno (Todos son bidireccionales)| ❌ Ninguno |
| **Disponibilidad en Arg.**| **Excelente (Muy alta)** | **Media-Alta** | **Media** |
| **Precio Relativo (DevKit)**| 💲 Económico (~$6.000-$8.000 ARS) | 💲💲 Medio-Alto (~$12.000-$18.000 ARS) | 💲 Muy Económico (~$5.000-$7.000 ARS)|

---

## 2. Análisis Detallado por Modelo

### A. ESP32 Clásico (ESP32-WROOM-32D / WROOM-32E)
Es el estándar del mercado desde hace años. 
*   **Pines y Recursos**: Cuenta con unos 26-28 GPIOs disponibles en placas de desarrollo (como el *NodeMCU-32S* o *ESP32 DevKit V1*). Posee 4 pines que son exclusivamente de entrada (**GPIO 34, 35, 36 y 39**), los cuales son perfectos para nuestras **entradas analógicas ADC1**, ya que no interfieren con las salidas.
*   **Disponibilidad en Argentina**: Máxima. Se consigue en cualquier casa de electrónica local (PatagoniaTec, Electrocomponentes, etc.) y MercadoLibre con entrega inmediata. Si se quema una placa, se reemplaza en el día.
*   **Desventaja**: No tiene USB nativo. Si diseñas la PCB para soldar el módulo WROOM de montaje superficial, tendrás que agregar el circuito del chip USB-a-UART (CH340C o CP2102) y su lógica de auto-reset, encareciendo el diseño. Si usas la placa DevKit como módulo insertable (tipo shield), esta desventaja desaparece.

### B. ESP32-S3 (ESP32-S3-WROOM-1)
Es el chip moderno de Espressif con vector de instrucciones para IA.
*   **Pines y Recursos**: Tiene más de 30 GPIOs útiles, todos bidireccionales con pull-ups/pull-downs internos configurables. 
*   **USB Nativo**: Esta es su mayor ventaja si diseñas la PCB desde el módulo SMD. El ESP32-S3 tiene soporte USB integrado en los pines GPIO 19 (D-) y 20 (D+). Solo necesitas soldar un puerto USB-C directo a esos pines y el chip se programa y depura solo, ahorrando componentes en tu BOM.
*   **Disponibilidad en Argentina**: Buena en tiendas especializadas en línea, aunque menos común en locales de mostrador tradicionales. Su costo es el más elevado de los tres.

### C. ESP32-C3 (ESP32-C3-MINI-1)
Basado en la nueva arquitectura abierta RISC-V, ideal para bajo consumo.
*   **Pines y Recursos**: Muy limitado. Solo dispone de unos 15 GPIOs útiles en formato DevKit.
*   **Incompatibilidad con nuestro diseño**:
    *   No tiene pines suficientes para manejar Ethernet (SPI de 6 pines) + RS485 (3 pines) + I2C (2 pines) + Ultrasonidos (5 pines) + 1-Wire (1 pin) + Analógicos (4 pines).
    *   Para usarlo, tendríamos que pasar funciones críticas como los receptores de Echo de los ultrasonidos (que miden tiempos en microsegundos) a expansores I2C, lo que es inviable debido a la latencia de bus I2C (provocaría un error de medición enorme en la distancia).
*   **Ideal para**: Nódulos satélite simples (ej. reemplazo del ESP-01), pero no para la placa concentradora universal.

---

## 3. Impacto del Método de Integración en el PCB

Al diseñar la PCB en Altium, tienes dos caminos que definen el costo y la elección del chip:

### Opción 1: Placa DevKit como Módulo Insertable (Recomendado para prototipos/Hogar)
Diseñas la placa principal con tiras de pines hembra (headers) donde pinchas una placa de desarrollo comercial (DevKit) completa.
*   **Ventajas**:
    *   Fácil reemplazo en caso de fallas (se saca y se pone otro).
    *   El circuito USB-UART y regulador de 3.3V auxiliar ya vienen resueltos en el DevKit.
    *   **Mejor opción**: **ESP32 Clásico DevKitC (38 pines)** o **ESP32-S3 DevKitC-1**.
*   **Desventajas**: Mayor altura física en el gabinete.

### Opción 2: Módulo SMD Soldado directamente a la PCB (Diseño Profesional/Industrial)
Diseñas la PCB integrando directamente el módulo metálico (ej. ESP32-WROOM-32E o ESP32-S3-WROOM-1).
*   **Ventajas**: Placa extremadamente delgada, estética industrial, menor costo por unidad si se fabrican en cantidad.
*   **Mejor opción**: **ESP32-S3-WROOM-1**. Al tener USB nativo, te ahorras poner el chip CH340 y sus componentes pasivos asociados, simplificando enormemente el ruteo en Altium.

---

## 4. Conclusión y Recomendación

1.  **Si vas a usar placas DevKit insertables (Shield)**:
    *   **Usa el ESP32 Clásico DevKit de 38 pines**. Es el más barato, hay stock de sobra en Argentina, y tiene pines de sobra para cubrir los 22 GPIOs nativos requeridos en la Opción B.
2.  **Si vas a diseñar con módulo SMD soldado**:
    *   **Usa el módulo ESP32-S3-WROOM-1**. La facilidad de ruteo que te da conectar el conector USB-C directo al chip (GPIO 19 y 20) compensa con creces el costo extra del chip frente al clásico.
3.  **Descarte**: El **ESP32-C3** queda descartado para esta placa concentradora por la falta de pines para los ultrasonidos directos y el módulo Ethernet.

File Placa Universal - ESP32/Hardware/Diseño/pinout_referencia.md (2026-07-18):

# Mapa de Pines (Pinout) de Referencia - Placa Universal ESP32-S3

Este documento es la **única fuente de verdad** para las conexiones físicas entre la placa de desarrollo **ESP32-S3 DevKitC-1** y los periféricos de la placa universal. Sirve tanto para el diseño del esquema electrónico como para las definiciones `#define` en los firmwares.

---

## 1. Resumen Gráfico de Asignación de Pines

| GPIO ESP32-S3 | Función | Tipo | Descripción / Restricciones |
| :---: | :---: | :---: | :--- |
| **GPIO 0** | BOOT / PRG | Entrada | Botón de Boot en DevKit (Strapping Pin - No usar para E/S) |
| **GPIO 1** | ANALOG_1 | Analógico (ADC1_CH0) | Entrada Analógica 1 (Apta para usar con WiFi activo) |
| **GPIO 2** | ANALOG_2 | Analógico (ADC1_CH1) | Entrada Analógica 2 (Apta para usar con WiFi activo) |
| **GPIO 3** | ANALOG_3 | Analógico (ADC1_CH2) | Entrada Analógica 3 (Apta para usar con WiFi activo) |
| **GPIO 4** | ANALOG_4 | Analógico (ADC1_CH3) | Entrada Analógica 4 (Apta para usar con WiFi activo) |
| **GPIO 5** | US_TRIG | Salida Digital | Trigger común para los 4 sensores ultrasónicos JSN-SR04T |
| **GPIO 6** | US_ECHO_1 | Entrada Digital | Echo del Sensor Ultrasónico 1 |
| **GPIO 7** | US_ECHO_2 | Entrada Digital | Echo del Sensor Ultrasónico 2 |
| **GPIO 8** | I2C_SDA | E/S Digital (I2C) | Bus I2C - Datos (con pull-up externo de 4.7k) |
| **GPIO 9** | I2C_SCL | Salida Digital (I2C) | Bus I2C - Reloj (con pull-up externo de 4.7k) |
| **GPIO 10** | MCP_INT | Entrada Digital | Interrupción activa en bajo de las entradas del MCP23017 |
| **GPIO 11** | SPI_MOSI | Salida Digital (SPI) | Bus SPI - Master Out Slave In |
| **GPIO 12** | SPI_MISO | Entrada Digital (SPI) | Bus SPI - Master In Slave Out |
| **GPIO 13** | SPI_SCLK | Salida Digital (SPI) | Bus SPI - Reloj de Serie |
| **GPIO 14** | ETH_CS | Salida Digital (SPI) | Chip Select para el módulo Ethernet W5500 |
| **GPIO 15** | US_ECHO_3 | Entrada Digital | Echo del Sensor Ultrasónico 3 |
| **GPIO 16** | US_ECHO_4 | Entrada Digital | Echo del Sensor Ultrasónico 4 |
| **GPIO 17** | ONE_WIRE | E/S Digital (1-Wire)| Bus de Temperatura (con pull-up de 4.7k) |
| **GPIO 18** | RS485_TX | Salida (UART2_TX) | Transmisión UART hacia el chip transceptor RS485 |
| **GPIO 19** | USB_D- | USB Nativo | Reservado para puerto USB-OTG de depuración/flasheo |
| **GPIO 20** | USB_D+ | USB Nativo | Reservado para puerto USB-OTG de depuración/flasheo |
| **GPIO 21** | RS485_RX | Entrada (UART2_RX) | Recepción UART desde el chip transceptor RS485 |
| **GPIO 38** | RS485_DE_RE | Salida Digital | Control de flujo dirección RS485 (1 = Transmitir, 0 = Recibir) |
| **GPIO 39** | ETH_RST | Salida Digital | Reset de hardware para el chip Ethernet W5500 |
| **GPIO 40** | ETH_INT | Entrada Digital | Interrupción de hardware del chip Ethernet W5500 |
| **GPIO 43** | UART0_TX | UART de Consola | Conectado al chip USB-to-UART del DevKit (Flasheo/Consola) |
| **GPIO 44** | UART0_RX | UART de Consola | Conectado al chip USB-to-UART del DevKit (Flasheo/Consola) |
| **GPIO 45** | Reservado | Strapping Pin | Deja flotante/LOW en arranque (Ajusta voltaje SPI Flash) |
| **GPIO 46** | Reservado | Strapping Pin | Deja flotante/LOW en arranque (Controla descarga de Boot) |
| **GPIO 47** | LIBRE | - | Disponible para expansiones en placa |
| **GPIO 48** | RGB_LED | Salida Digital | Conectado al LED RGB NeoPixel interno del DevKitC-1 |

---

## 2. Notas de Diseño Críticas para Hardware y Firmware

### ⚠️ Regla de Oro sobre las Entradas Analógicas:
Los pines analógicos asignados (**GPIO 1, 2, 3 y 4**) pertenecen al **ADC1** del ESP32-S3. 
* *Razón*: El ESP32-S3 tiene dos convertidores analógicos (ADC1 y ADC2). El ADC2 se desconecta por hardware internamente cuando la radio WiFi o Bluetooth está activa. Al usar canales del ADC1, podemos leer sensores analógicos en tiempo real sin interferir con las comunicaciones inalámbricas.

### 🔌 Divisores de Tensión obligatorios para Ultrasonidos (Echo):
Los sensores de ultrasonido JSN-SR04T se alimentan y operan a **5V**. Por lo tanto, los pines `US_ECHO_x` entregarán un pulso de 5V.
* *Solución*: En el PCB, coloca un divisor resistivo simple (ej. **1k Ohm en serie** y **2k Ohm a GND**) en cada una de las 4 líneas de Echo (**GPIO 6, 7, 15 y 16**) para reducir el pulso a 3.3V antes de entrar al microcontrolador.

### 🛡️ Pines de Arranque (Strapping Pins) Protegidos:
Evitamos conectar periféricos de entrada/salida que puedan forzar estados lógicos en los pines **GPIO 0, 45 y 46** durante el arranque, ya que esto podría impedir que el ESP32-S3 inicie correctamente o ponerlo en modo de flasheo permanente.

---

## 3. Código C++ de Cabecera Común (`pinout.h`)

Este fragmento de código puede copiarse directamente en la carpeta `/Librerias_Compartidas/` para ser incluido en los tres proyectos de firmware:

```cpp
#ifndef PINOUT_UNIVERSAL_H
#define PINOUT_UNIVERSAL_H

// --- BUSES DE COMUNICACIÓN ---
#define I2C_SDA_PIN      8
#define I2C_SCL_PIN      9
#define ONE_WIRE_PIN     17

// --- ENTRADAS ANALÓGICAS (ADC1) ---
#define ANALOG_1_PIN     1
#define ANALOG_2_PIN     2
#define ANALOG_3_PIN     3
#define ANALOG_4_PIN     4

// --- SENSORES DE ULTRASONIDO ---
#define US_TRIG_PIN      5
#define US_ECHO_1_PIN    6
#define US_ECHO_2_PIN    7
#define US_ECHO_3_PIN    15
#define US_ECHO_4_PIN    16

// --- ETHERNET SPI (W5500) ---
#define ETH_SPI_MOSI    11
#define ETH_SPI_MISO    12
#define ETH_SPI_SCLK    13
#define ETH_CS_PIN      14
#define ETH_RST_PIN     39
#define ETH_INT_PIN     40

// --- BUS INDUSTRIAL RS485 (UART2) ---
#define RS485_TX_PIN    18
#define RS485_RX_PIN    21
#define RS485_DE_RE_PIN 38

// --- EXPANSOR I2C (MCP23017) ---
#define MCP_INT_PIN     10

#endif // PINOUT_UNIVERSAL_H
```

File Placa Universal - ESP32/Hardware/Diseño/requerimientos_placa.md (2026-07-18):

# Documento de Requerimientos - Placa Universal ESP32-S3

Este documento define las especificaciones técnicas, eléctricas y funcionales para el diseño del hardware de la Placa Universal basada en el **ESP32-S3**. 

---

## 1. Resumen de Requerimientos de Entrada/Salida y Protocolos

El diseño se centra en una **arquitectura basada en expansores de puertos (Opción B)** para garantizar la disponibilidad de pines y la escalabilidad del sistema. 

Para reducir el tamaño de la PCB, simplificar el ruteo y aumentar la seguridad eléctrica, **no se integrarán relés mecánicos ni de estado sólido (SSR) directamente en la placa**. En su lugar, se dispondrán salidas a nivel lógico (cabezales de pines o borneras pequeñas) para conectar módulos externos.

### Entradas/Salidas y Conectores:
*   **16 Entradas Digitales**: Aisladas mediante optoacopladores para cables largos (sensores PIR, magnéticos de alarmas, pulsadores).
*   **6 Salidas para Relés de Estado Sólido (SSR) Externos**:
    *   Salidas lógicas de control a borneras o pines de conexión.
    *   Pensadas para conectar un módulo SSR externo comercial de 4 canales (tipo G3MB-202P) + 2 canales adicionales para relés SSR de potencia industriales externos (ej. 60A / 24-380VAC).
*   **4 Salidas MOSFET de Potencia en placa**: Para conmutar cargas DC de 12V de forma directa (Sirena de alarma, tiras LED, electroválvulas, etc.).
*   **4 Entradas Analógicas Nativas**: Para mediciones de sensores analógicos directos (ej. nivel de agua por presión/corriente, monitoreo de tensión de baterías o sensores de luz).
*   **4 Puertos para Sensores Ultrasonido (JSN-SR04T)**: Conexión mediante 5 pines nativos (1 pin de Trigger común y 4 pines de Echo dedicados).
*   **Buses de Comunicación**:
    *   **I2C**: Para pantallas de configuración (OLED), sensores de clima (BME280) y periféricos de expansión.
    *   **SPI**: Reservado para comunicación rápida (pantallas TFT, lector RFID o periféricos).
    *   **1-Wire**: Bornera con pull-up para sensores de temperatura DS18B20 en cascada.
    *   **RS485 Aislado**: Bus industrial con transceptor aislado galvánicamente para comunicación de larga distancia (Modbus).
    *   **Ethernet**: Conexión cableada redundante mediante módulo SPI **W5500**.

---

## 2. Arquitectura de Expansión de Puertos y Distribución de Pines

Utilizamos dos expansores de puertos **MCP23017** conectados al bus **I2C**, lo que permite manejar las 16 entradas y las 10 salidas digitales consumiendo únicamente 2 pines de control del ESP32-S3 (más el pin de interrupción).

### A. Mapeo de los Expansores (MCP23017)
*   **Expansor 1 (MCP23017 - Dirección I2C 0x20)**:
    *   **GPIO A0 a B7 (16 pines)**: Conectados a las **16 entradas digitales optoacopladas**.
    *   *Interrupción*: Pin INTA/INTB conectado al ESP32-S3 para detectar flancos de subida/bajada de forma inmediata sin sobrecargar la CPU haciendo polling.
*   **Expansor 2 (MCP23017 - Dirección I2C 0x21)**:
    *   **GPIO A0 a A5 (6 pines)**: Conectados a las **6 salidas de control de SSR externos**.
    *   **GPIO A6 a B1 (4 pines)**: Conectados a las compuertas de los **4 MOSFETs de potencia DC en placa**.
    *   **GPIO B2 a B7 (6 pines)**: **Pines Libres** para futuras ampliaciones (LEDs de estado, zumbadores de sistema, configuración, etc.).

### B. Distribución de Pines del ESP32-S3
1.  **Bus I2C (SDA, SCL)**: **2 pines**. Conexión de ambos MCP23017 y sensores locales.
2.  **Interrupción de Entradas (MCP1_INT)**: **1 pin**.
3.  **Entradas Analógicas**: **4 pines nativos** (conectados a los canales de ADC del ESP32-S3).
4.  **4 Sensores por Ultrasonido (JSN-SR04T)**: **5 pines nativos** (1 Trigger común + 4 Echo independientes).
5.  **Bus 1-Wire**: **1 pin nativo** (para sensores de temperatura DS18B20).
6.  **RS485 Aislado**: **3 pines nativos** (TX, RX del UART dedicado + pin DE/RE para el control de flujo).
7.  **Ethernet (Módulo SPI W5500)**: **6 pines nativos** (MOSI, MISO, SCK, CS, RST, INT).

*   **Total de GPIOs del ESP32-S3 en uso**: **22 pines nativos**.
*   **Pines Libres en el DevKit**: Quedan libres alrededor de 6 a 8 GPIOs nativos para propósitos adicionales.

---

## 3. Requerimientos de Protección Eléctrica (Detallados)

Al no tener relés de alterna (AC) dentro de la placa, el diseño del PCB es **100% de baja tensión (12V / 5V / 3.3V)**, lo que elimina el peligro de arcos de AC y reduce drásticamente el ruido inductivo en la placa principal.

### A. Entradas Digitales (16 Canales)
*   **Optoacopladores (PC817)**: Aislamiento total de las líneas físicas externas.
*   **Filtros RC pasivos**: Resistencia limitadora de corriente y capacitor cerámico de 100nF para suprimir transitorios causados por inducción en cables largos de sensores de alarma.
*   **Diodos contra Polaridad Inversa**: Diodo en paralelo inverso en el LED del optoacoplador para proteger el canal en caso de error en el cableado externo.

### B. Entradas Analógicas (4 Canales)
*   **Diodos Zener/TVS de 3.3V**: En paralelo para limitar la tensión de entrada y proteger el convertidor ADC del ESP32-S3.
*   **Filtro RC**: Estabiliza la medición de señales analógicas.

### C. Salidas de Control de SSR Externos (6 Canales)
*   **Buffer de Corriente (ULN2803)**: Las 6 líneas del expansor controlan un integrado ULN2803 que actúa como buffer (drenando la corriente de control de los relés a masa), evitando exigir de corriente al MCP23017.
*   **Conectores dedicados**: Exponer las salidas con pines de señal, alimentación (5V) y masa (GND).

### D. Salidas MOSFET de Potencia DC (4 Canales)
*   **MOSFETs Logic-Level (ej. AOD4184 en SMD o IRLZ44N en TH)**: Controlados desde el ULN2803 o directamente desde el expansor usando resistencias de compuerta y pull-down de 10k Ohm para evitar activaciones aleatorias durante el arranque.
*   **Diodos Schottky Flyback**: Diodo SMD (ej. SS34) en paralelo con los bornes de salida para proteger el MOSFET del pico inductivo de solenoides o sirenas.

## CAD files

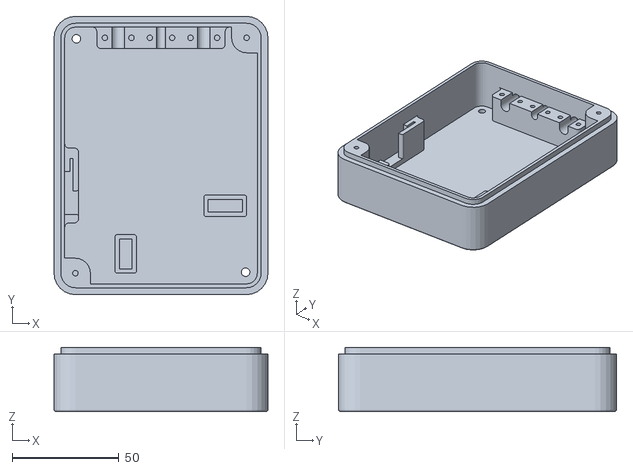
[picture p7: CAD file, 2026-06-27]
Diseño y Hardware/Modelos 3D y Planos/Gabinete Central/Central de alarma_B.stl
100.0 x 130.0 x 30.0

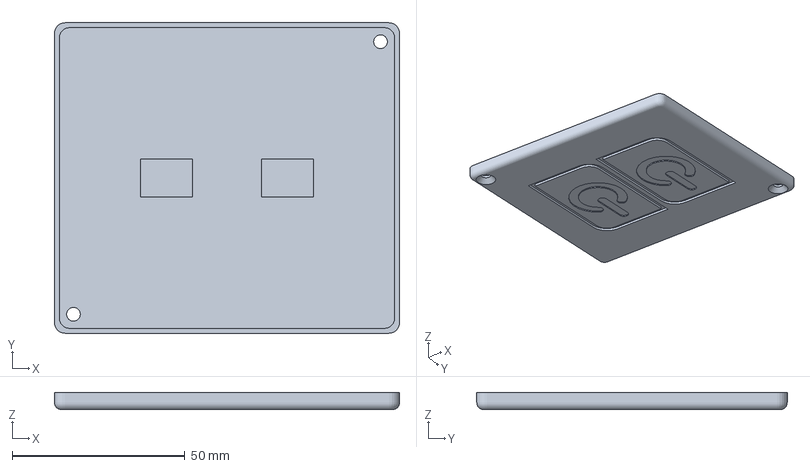
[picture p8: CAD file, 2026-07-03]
Diseño y Hardware/Modelos 3D y Planos/Gabinete ESP01/Gabinetes A.3mf
100.0 x 90.0 x 5.00 mm

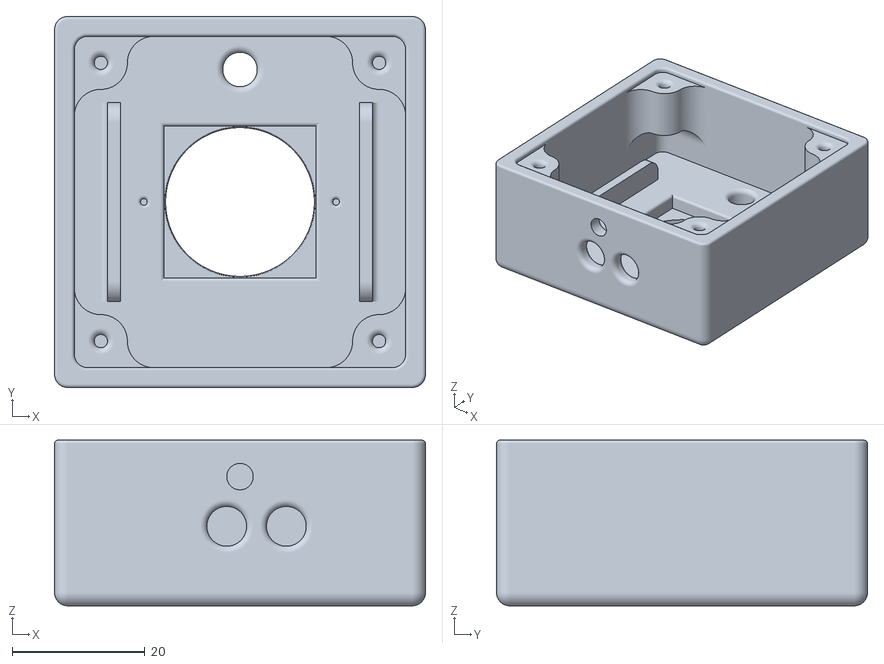
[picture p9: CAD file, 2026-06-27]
Diseño y Hardware/Modelos 3D y Planos/Gabinete Frente/Carcasa sensor PIR - A.stl
56.0 x 56.0 x 25.0

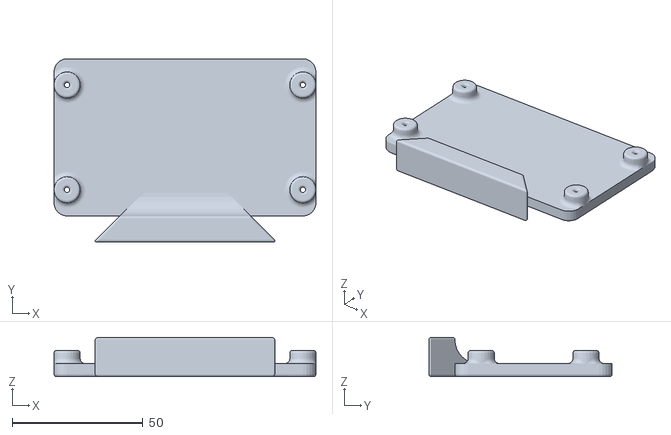
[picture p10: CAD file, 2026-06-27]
Diseño y Hardware/Modelos 3D y Planos/Soportes Generales/Soporte - Placa expansora.stl
100.0 x 70.0 x 15.0

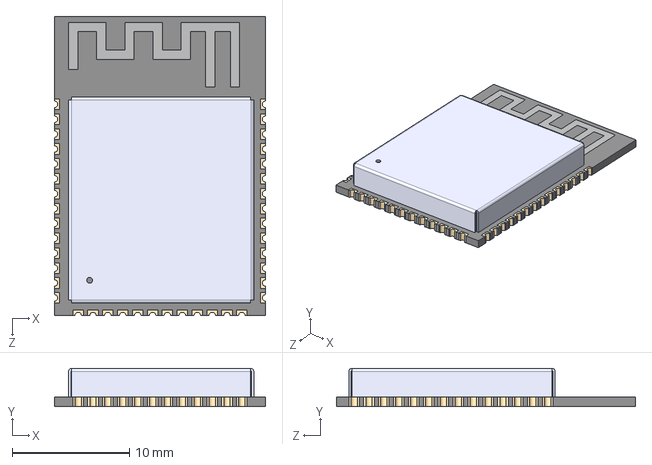
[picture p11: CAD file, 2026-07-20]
Placa Universal - ESP32/Hardware/Proyecto PCB/Librerías/ESP32-S3-WROOM-1-N8R8.STEP
18.0 x 3.25 x 25.5 mm

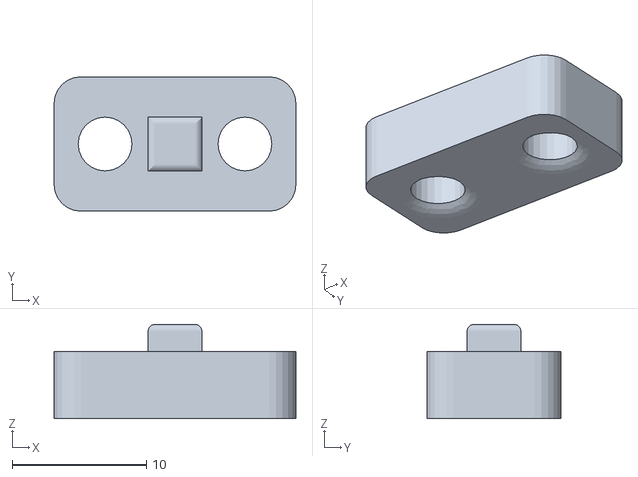
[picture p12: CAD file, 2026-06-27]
Diseño y Hardware/Modelos 3D y Planos/Gabinete Central/Central de alarma_D.stl
18.0 x 10.00 x 7.00

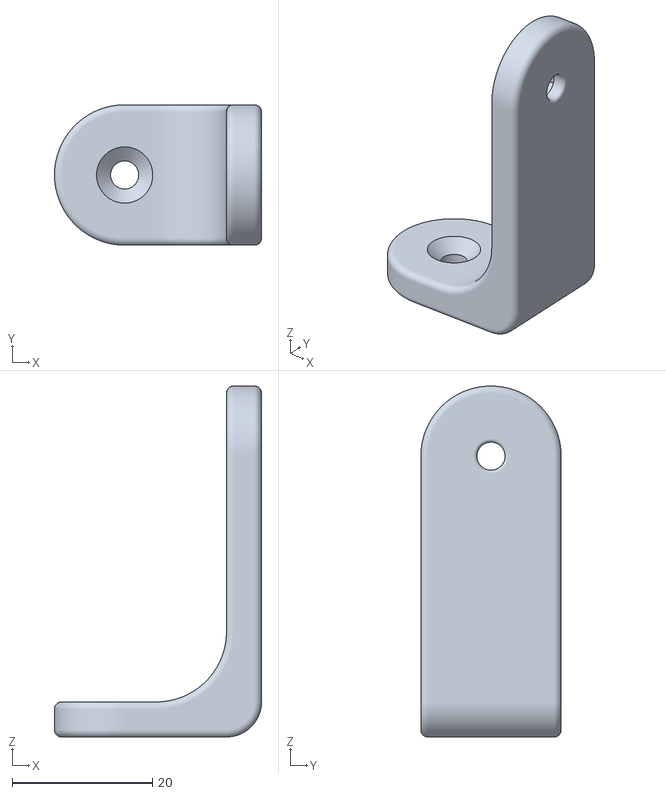
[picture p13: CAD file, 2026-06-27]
Diseño y Hardware/Modelos 3D y Planos/Gabinete Frente/Carcasa sensor PIR - C.stl
29.5 x 20.0 x 50.0

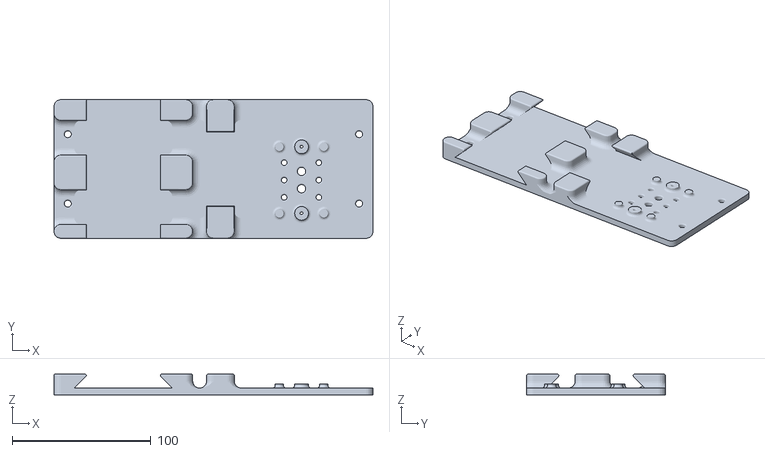
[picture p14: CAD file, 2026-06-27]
Diseño y Hardware/Modelos 3D y Planos/Soportes Generales/Soporte completo.stl
230.0 x 100.0 x 15.1

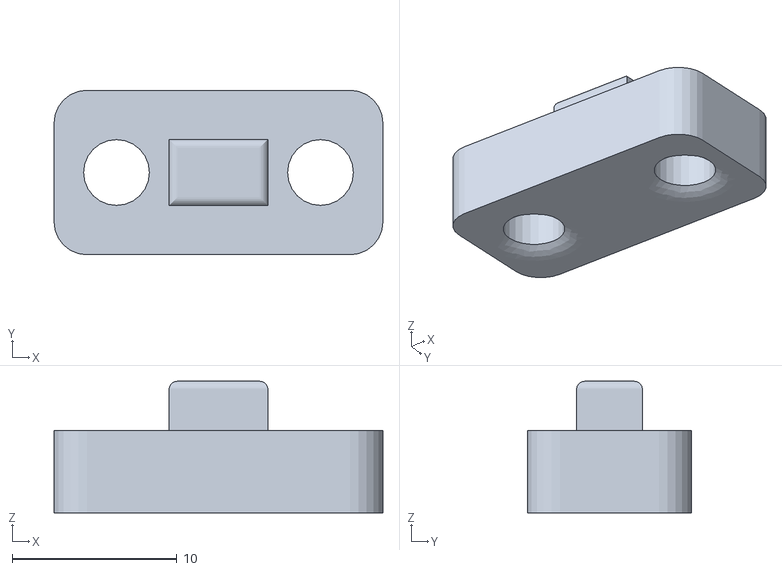
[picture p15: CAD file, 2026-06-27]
Diseño y Hardware/Modelos 3D y Planos/Gabinete Central/Central de alarma_C.stl
20.0 x 10.00 x 8.00

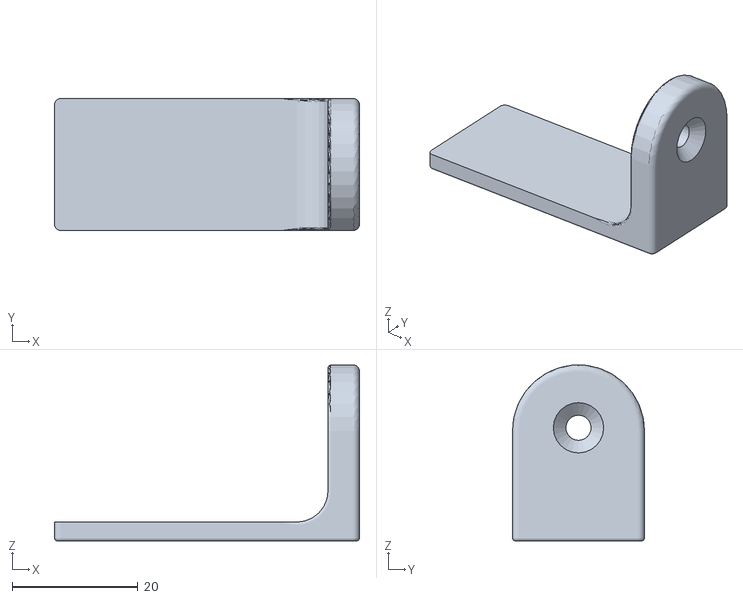
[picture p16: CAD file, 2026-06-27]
Diseño y Hardware/Modelos 3D y Planos/Gabinete Frente/Carcasa sensor uW - B.stl
48.5 x 21.0 x 28.0

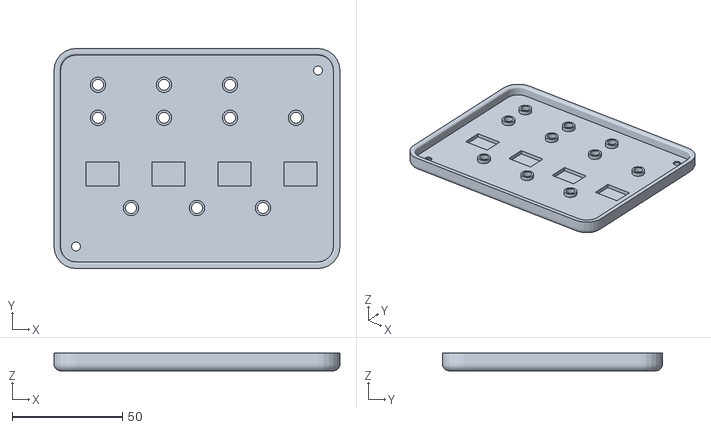
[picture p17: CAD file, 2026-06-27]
Diseño y Hardware/Modelos 3D y Planos/Gabinete Central/Central de alarma_A.stl
130.0 x 100.0 x 8.00

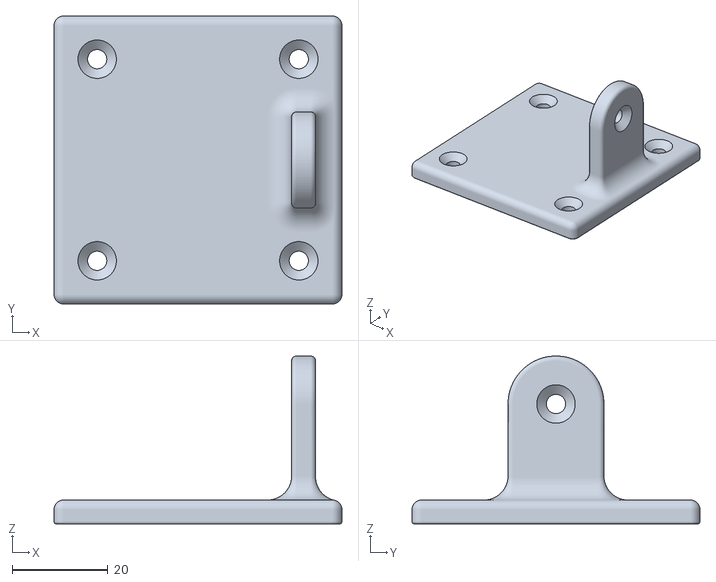
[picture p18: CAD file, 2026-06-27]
Diseño y Hardware/Modelos 3D y Planos/Gabinete Frente/Carcasa sensor PIR - B.stl
60.0 x 60.0 x 35.0

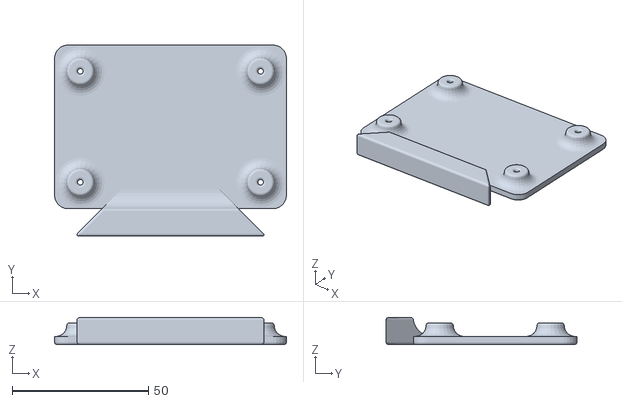
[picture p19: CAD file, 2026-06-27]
Diseño y Hardware/Modelos 3D y Planos/Soportes Generales/Soporte - ESP32.stl
85.0 x 70.0 x 10.00

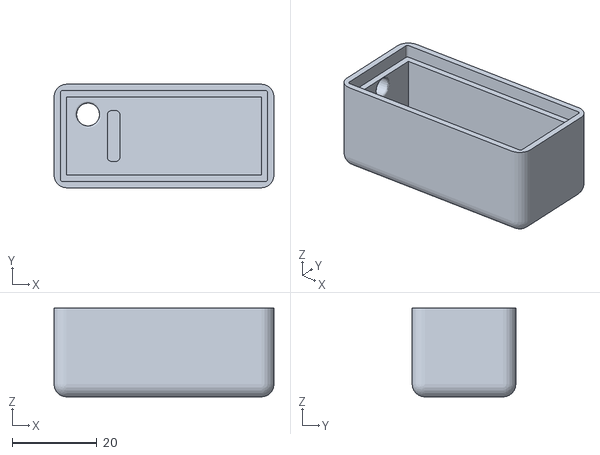
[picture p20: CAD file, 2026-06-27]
Diseño y Hardware/Modelos 3D y Planos/Gabinete Frente/Carcasa sensor uW - A.stl
52.0 x 24.5 x 21.0

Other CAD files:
Diseño y Hardware/Modelos 3D y Planos/Gabinetes y carcasas.dwg
Diseño y Hardware/Modelos 3D y Planos/Gabinete ESP01/Gabinetes B.stl
Diseño y Hardware/Modelos 3D y Planos/Soportes Generales/Soporte - Rele 4 canales.3mf
Diseño y Hardware/Modelos 3D y Planos/Gabinete Frente/Base relés.stl
Diseño y Hardware/Modelos 3D y Planos/Gabinete ESP01/Gabinetes A.stl
Diseño y Hardware/Modelos 3D y Planos/Gabinete Frente/Base electrónica.stl
Diseño y Hardware/Modelos 3D y Planos/Gabinete Frente/Carcasa sensor uW - C.stl
Diseño y Hardware/Modelos 3D y Planos/Soportes Generales/Soporte - Rele 4 canales.stl

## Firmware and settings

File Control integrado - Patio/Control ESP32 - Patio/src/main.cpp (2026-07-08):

// =========================
// Firmware ESP32 – Etapa 1
// =========================

#include <Arduino.h>
#include <globales.h>
#include <conexiones/conexiones.h>
#include <sensores/sensores.h>
#include <WiFi.h>
#include <ESPmDNS.h>
#include <WiFiUdp.h>
#include <ArduinoOTA.h>
#include <PubSubClient.h>
#include <DHT.h>
#include <ArduinoJson.h>
#include <Ticker.h>
#include <WebServer.h>
#include <OneWire.h>
#include <DallasTemperature.h>
#include <SPI.h>

// =======================
// VARIABLES GLOBALES
// =======================
float TEMPERATURA = 0;
float HUMEDAD = 0;
int Luz = 0;

float tempPileta = 0;
float tempColector = 0;

int ValorNoche = 500;
int valNocheHist = 0;
int histeresisLuz = 20;

byte reflectoresConf = 0;
bool reflectoresST = false;

byte bombaCisternaConf = 0;
bool bombaCisternaST = false;

byte bombaTanqueConf = 0;
bool bombaTanqueST = false;

byte bombaPiletaConf = 0;
bool bombaPiletaST = false;

byte luzPiletaConf = 0;
bool luzPiletaST = false;

byte luzGaleriaConf = 0;
bool luzGaleriaST = false;

byte luzGaleriaBordeConf = 0;
bool luzGaleriaBordeST = false;

bool aux1En = false;
bool aux2En = false;

float tempSet = 35.0;
float tempDif_on = 10.0;  // Diferencia para encender bomba
float tempDif_off = 5.0;  // Diferencia para apagar bomba

volatile int enviaDataCounter = 0;
int intervalData = 60;
bool Telemetria = false;

int var = 0;
char datos[40];

unsigned long ultimaAccionBomba = 0;     // timestamp del último cambio
unsigned long tiempoEncendida = 0;       // cuánto tiempo lleva encendida

bool IntercambioST = false;
float piletaRaw = 0;
float colectorRaw = 0;

// Configurables
unsigned long minOnTime  = 60000;   // 1 min encendida mínimos
unsigned long minOffTime =  300000;   // 5 min apagada mínimo
unsigned long maxOnTime  = 900000;   // 15 min máximo encendida

// =======================
// OBJETOS Y HORARIOS
// =======================
#include <Preferences.h>

ScheduleRule schedules[8];
int ultimoMinutoEvaluado = -1;

bool obtenerHoraLocal(struct tm &infoTiempo) {
  time_t ahora = time(nullptr);
  if (ahora < 1600000000) {
    return false;
  }
  localtime_r(&ahora, &infoTiempo);
  return true;
}

void guardarSchedules() {
  Preferences prefs;
  prefs.begin("horarios", false);
  
  DynamicJsonDocument doc(1500);
  JsonArray arr = doc.to<JsonArray>();
  for (int i = 0; i < 8; i++) {
    JsonObject obj = arr.createNestedObject();
    obj["active"] = schedules[i].active;
    obj["hour"] = schedules[i].hour;
    obj["minute"] = schedules[i].minute;
    obj["weekdays"] = schedules[i].weekdays;
    obj["target"] = schedules[i].target;
    obj["action"] = schedules[i].action;
  }
  
  String jsonStr;
  serializeJson(doc, jsonStr);
  prefs.putString("schedules", jsonStr);
  prefs.end();
  Serial.println("Horarios guardados en Preferences.");
}

void cargarSchedules() {
  Preferences prefs;
  prefs.begin("horarios", true);
  String jsonStr = prefs.getString("schedules", "");
  prefs.end();

  // Inicializar por defecto
  for (int i = 0; i < 8; i++) {
    schedules[i].active = false;
    schedules[i].hour = 0;
    schedules[i].minute = 0;
    schedules[i].weekdays = 0;
    schedules[i].target = 0;
    schedules[i].action = 0;
  }

  if (jsonStr.length() > 0) {
    DynamicJsonDocument doc(1500);
    DeserializationError error = deserializeJson(doc, jsonStr);
    if (!error) {
      JsonArray arr = doc.as<JsonArray>();
      int idx = 0;
      for (JsonObject obj : arr) {
        if (idx >= 8) break;
        schedules[idx].active = obj["active"] | false;
        schedules[idx].hour = obj["hour"] | 0;
        schedules[idx].minute = obj["minute"] | 0;
        schedules[idx].weekdays = obj["weekdays"] | 0;
        schedules[idx].target = obj["target"] | 0;
        schedules[idx].action = obj["action"] | 0;
        idx++;
      }
      Serial.println("Horarios cargados exitosamente de Preferences.");
    } else {
      Serial.println("Fallo al deserializar horarios de Preferences.");
    }
  } else {
    Serial.println("No hay horarios guardados en Preferences.");
  }
}

Ticker secondTicker;

void crearEstadoJson(JsonDocument& doc)
{
  doc["tempPileta"] = tempPileta;
  doc["tempColector"] = tempColector;
  doc["bombaPiletaST"] = bombaPiletaST;
  doc["bombaPiletaConf"] = bombaPiletaConf;
  doc["tempSet"] = tempSet;
  doc["tempDif_on"] = tempDif_on;
  doc["tempDif_off"] = tempDif_off;
  doc["minOnTime"] = minOnTime;
  doc["minOffTime"] = minOffTime;
  doc["maxOnTime"] = maxOnTime;
  doc["bombaCisternaST"] = bombaCisternaST;
  doc["bombaCisternaConf"] = bombaCisternaConf;
  doc["bombaTanqueST"] = bombaTanqueST;
  doc["bombaTanqueConf"] = bombaTanqueConf;
  doc["reflectoresST"] = reflectoresST;
  doc["reflectoresConf"] = reflectoresConf;
  doc["luzPiletaST"] = luzPiletaST;
  doc["luzPiletaConf"] = luzPiletaConf;
  doc["luzGaleriaST"] = luzGaleriaST;
  doc["luzGaleriaConf"] = luzGaleriaConf;
  doc["luzGaleriaBordeST"] = luzGaleriaBordeST;
  doc["luzGaleriaBordeConf"] = luzGaleriaBordeConf;
  doc["luzAmbiente"] = Luz;
  doc["nivelAgua"] = nivelAguaST;
  doc["tempTecho"] = TEMPERATURA;
  doc["humTecho"] = HUMEDAD;
  doc["IntercambioST"] = IntercambioST;
  doc["tempPiletaCrudo"] = piletaRaw;
  doc["tempColectorCrudo"] = colectorRaw;
  doc["aux1En"] = aux1En;
  doc["aux2En"] = aux2En;

  JsonArray schedArr = doc.createNestedArray("schedules");
  for (int i = 0; i < 8; i++) {
    JsonObject obj = schedArr.createNestedObject();
    obj["active"] = schedules[i].active;
    obj["hour"] = schedules[i].hour;
    obj["minute"] = schedules[i].minute;
    obj["weekdays"] = schedules[i].weekdays;
    obj["target"] = schedules[i].target;
    obj["action"] = schedules[i].action;
  }
}

void procesarComandosJson(JsonDocument& doc)
{
  bool configChanged = false;

  if (doc.containsKey("intervalData")) { intervalData = doc["intervalData"]; }
  if (doc.containsKey("tempDif_on")) { tempDif_on = doc["tempDif_on"]; }
  if (doc.containsKey("tempDif_off")) { tempDif_off = doc["tempDif_off"]; }
  if (doc.containsKey("tempSet")) { tempSet = doc["tempSet"]; }
  if (doc.containsKey("minOnTime")) { minOnTime = doc["minOnTime"]; }
  if (doc.containsKey("minOffTime")) { minOffTime = doc["minOffTime"]; }
  if (doc.containsKey("maxOnTime")) { maxOnTime = doc["maxOnTime"]; }
  
  if (doc.containsKey("bombaPiletaConf")) { bombaPiletaConf = doc["bombaPiletaConf"]; }
  if (doc.containsKey("bombaCisternaConf")) { bombaCisternaConf = doc["bombaCisternaConf"]; }
  if (doc.containsKey("bombaTanqueConf")) { bombaTanqueConf = doc["bombaTanqueConf"]; }
  if (doc.containsKey("reflectoresConf")) { reflectoresConf = doc["reflectoresConf"]; }
  if (doc.containsKey("luzPiletaConf")) { luzPiletaConf = doc["luzPiletaConf"]; }
  if (doc.containsKey("luzGaleriaConf")) { luzGaleriaConf = doc["luzGaleriaConf"]; }
  if (doc.containsKey("luzGaleriaBordeConf")) { luzGaleriaBordeConf = doc["luzGaleriaBordeConf"]; }
  
  if (doc.containsKey("aux1En")) { aux1En = doc["aux1En"]; }
  if (doc.containsKey("aux2En")) { aux2En = doc["aux2En"]; }
  
  if (doc.containsKey("IntercambioST")) {
    bool nuevo = doc["IntercambioST"];
    if (nuevo != IntercambioST)
    {
        IntercambioST = nuevo;
        guardarIntercambioST();
    }
  }
  
  if (doc.containsKey("patioSchedules") || doc.containsKey("schedules")) {
    JsonArray schedArr = doc.containsKey("patioSchedules") ? doc["patioSchedules"].as<JsonArray>() : doc["schedules"].as<JsonArray>();
    int idx = 0;
    for (JsonObject obj : schedArr) {
      if (idx >= 8) break;
      schedules[idx].active = obj["active"] | false;
      schedules[idx].hour = obj["hour"] | 0;
      schedules[idx].minute = obj["minute"] | 0;
      schedules[idx].weekdays = obj["weekdays"] | 0;
      schedules[idx].target = obj["target"] | 0;
      schedules[idx].action = obj["action"] | 0;
      idx++;
    }
    for (int i = idx; i < 8; i++) {
      schedules[i].active = false;
    }
    guardarSchedules();
    configChanged = true;
  }
  
  if (doc.containsKey("Telemetria")) Telemetria = doc["Telemetria"];
  
  if (configChanged) {
    actuadores();
  }
}

void enviarDatos()
{
  DynamicJsonDocument doc(2048);
  crearEstadoJson(doc);

  char buffer[1500];
  size_t n = serializeJson(doc, buffer, sizeof(buffer));

  mqttClient.publish("BALH142N1788/Patio", buffer, n);
}

// =======================
// BOMBA POR DIFERENCIA TÉRMICA
// =======================
void controlBombaPileta()
{
  float dif = tempColector - tempPileta;
  unsigned long ahora = millis();

  bool estadoPrevio = bombaPiletaST;   // Guardar estado anterior

  switch (bombaPiletaConf)
  {
      // =====================================================
      // 1 - Encendido manual
      // =====================================================
      case 1:
          if (!bombaPiletaST) {
              digitalWrite(bombaPileta, HIGH);   // ENCENDER (lógica directa)
              bombaPiletaST = true;
              ultimaAccionBomba = ahora;
              tiempoEncendida = ahora;
          }
          break;

      // =====================================================
      // 2 - Modo automático
      // =====================================================
      case 2:
      {
          bool deseoEncender =  (dif >= tempDif_on) && (tempPileta < tempSet);
          bool deseoApagar   =  (dif <= tempDif_off) || (tempPileta >= tempSet);

          // -------------------------------
          // MAX ON TIME (protección)
          // -------------------------------
          if (bombaPiletaST && (ahora - tiempoEncendida >= maxOnTime))
          {
              digitalWrite(bombaPileta, LOW);    // APAGAR
              bombaPiletaST = false;
              ultimaAccionBomba = ahora;
              break;
          }

          // -------------------------------
          // MIN OFF TIME (protección)
          // -------------------------------
          if (!bombaPiletaST && deseoEncender)
          {
              if (ahora - ultimaAccionBomba < minOffTime)
                  break;
          }

          // -------------------------------
          // MIN ON TIME (protección)
          // -------------------------------
          if (bombaPiletaST && deseoApagar)
          {
              if (ahora - tiempoEncendida < minOnTime)
                  break;
          }

          // -------------------------------
          // ENCENDER por condición térmica
          // -------------------------------
          if (deseoEncender && !bombaPiletaST)
          {
              digitalWrite(bombaPileta, HIGH);   // ENCENDER
              bombaPiletaST = true;
              ultimaAccionBomba = ahora;
              tiempoEncendida = ahora;
          }
          // -------------------------------
          // APAGAR por condición térmica
          // -------------------------------
          else if (deseoApagar && bombaPiletaST)
          {
              digitalWrite(bombaPileta, LOW);    // APAGAR
              bombaPiletaST = false;
              ultimaAccionBomba = ahora;
          }
      }
      break;

      // =====================================================
      // 0 y otros – apagado seguro
      // =====================================================
      default:
          if (bombaPiletaST) {
              digitalWrite(bombaPileta, LOW);     // APAGAR
              bombaPiletaST = false;
              ultimaAccionBomba = ahora;
          }
          break;
  }

  // =====================================================
  // Publicación automática solo si hubo cambio real
  // =====================================================
  if (bombaPiletaST != estadoPrevio)
      enviarDatos();
}

// =======================
// TICKER
// =======================
void cadaSegundo()
{
  enviaDataCounter++;
  if (enviaDataCounter >= intervalData)
  {
    enviaDataCounter = 0;
    Telemetria = true;
  }
}

void actuadores()
{
  if (bombaPiletaConf == 0)
  {
    digitalWrite(bombaPileta, LOW);       // Apaga la bomba
    bombaPiletaST = false;
  }
  else if (bombaPiletaConf == 1)
  {
    digitalWrite(bombaPileta, HIGH);    // Prende la bomba
    bombaPiletaST = true;
  }

  if (bombaCisternaConf == 0)
  {
    digitalWrite(bombaCisterna, HIGH);       // Apaga la bomba
    bombaCisternaST = false;
  }
  else if (bombaCisternaConf == 1)
  {
    digitalWrite(bombaCisterna, LOW);    // Prende la bomba
    bombaCisternaST = true;
  }

  if (bombaTanqueConf == 0)
  {
    digitalWrite(bombaTanque, HIGH);       // Apaga la bomba
    bombaTanqueST = false;
  }
  else if (bombaTanqueConf == 1)
  {
    digitalWrite(bombaTanque, LOW);    // Prende la bomba
    bombaTanqueST = true;
  }

  if (reflectoresConf == 1 || (reflectoresConf == 2 && Luz > valNocheHist))
  {
    digitalWrite(Reflectores, HIGH);       // Enciende reflectores
    reflectoresST = true;
  }
  else 
  {
    digitalWrite(Reflectores, LOW);    // Cualquier otro caso, la apaga
    reflectoresST = false;
  }

  if (luzPiletaConf == 1 || (luzPiletaConf == 2 && Luz > valNocheHist))
  {
    digitalWrite(luzPileta, LOW);       // Enciende luz de galeria
    luzPiletaST = true;
  }
  else 
  {
    digitalWrite(luzPileta, HIGH);    // Cualquier otro caso, la apaga
    luzPiletaST = false;
  }

  if (luzGaleriaConf == 1 || (luzGaleriaConf == 2 && Luz > valNocheHist))
  {
    digitalWrite(luzGaleria, LOW);       // Enciende luz de galeria
    luzGaleriaST = true;
  }
  else 
  {
    digitalWrite(luzGaleria, HIGH);    // Cualquier otro caso, la apaga
    luzGaleriaST = false;
  }

  if (luzGaleriaBordeConf == 1 || (luzGaleriaBordeConf == 2 && Luz > valNocheHist))
  {
    digitalWrite(luzGaleriaBorde, LOW);       // Enciende luz de galeria
    luzGaleriaBordeST = true;
  }
  else 
  {
    digitalWrite(luzGaleriaBorde, HIGH);    // Cualquier otro caso, la apaga
    luzGaleriaBordeST = false;
  }

  digitalWrite(salidaAux1, aux1En ? LOW : HIGH);  // Relé de lógica inversa
  digitalWrite(salidaAux2, aux2En ? LOW : HIGH);  // Relé de lógica inversa
}

void evaluarHorarios() {
  struct tm infoTiempo;
  if (!obtenerHoraLocal(infoTiempo)) {
    return; // Esperar a que NTP sincronice
  }

  // Ejecutar solo al cambiar de minuto
  if (infoTiempo.tm_min == ultimoMinutoEvaluado) {
    return;
  }
  ultimoMinutoEvaluado = infoTiempo.tm_min;

  int diaHoy = infoTiempo.tm_wday; // 0=Domingo, 1=Lunes, ..., 6=Sábado
  int horaHoy = infoTiempo.tm_hour;
  int minHoy = infoTiempo.tm_min;

  bool configChanged = false;

  for (int i = 0; i < 8; i++) {
    if (!schedules[i].active) continue;

    // Verificar si el día de hoy está en la máscara de bits
    if (!(schedules[i].weekdays & (1 << diaHoy))) continue;

    // Verificar si coincide la hora y minuto
    if (schedules[i].hour == horaHoy && schedules[i].minute == minHoy) {
      int target = schedules[i].target;
      int action = schedules[i].action;

      // 0: Reflectores, 1: Luz Pileta, 2: Luz Galería, 3: Luz Galería Borde, 4: Bomba Pileta, 5: Bomba Cisterna, 6: Bomba Tanque
      if (target == 0) {
        reflectoresConf = action;
        configChanged = true;
        Serial.printf("Horario: reflectoresConf cambiado a %d\n", action);
      } else if (target == 1) {
        luzPiletaConf = action;
        configChanged = true;
        Serial.printf("Horario: luzPiletaConf cambiado a %d\n", action);
      } else if (target == 2) {
        luzGaleriaConf = action;
        configChanged = true;
        Serial.printf("Horario: luzGaleriaConf cambiado a %d\n", action);
      } else if (target == 3) {
        luzGaleriaBordeConf = action;
        configChanged = true;
        Serial.printf("Horario: luzGaleriaBordeConf cambiado a %d\n", action);
      } else if (target == 4) {
        bombaPiletaConf = action;
        configChanged = true;
        Serial.printf("Horario: bombaPiletaConf cambiado a %d\n", action);
      } else if (target == 5) {
        bombaCisternaConf = action;
        configChanged = true;
        Serial.printf("Horario: bombaCisternaConf cambiado a %d\n", action);
      } else if (target == 6) {
        bombaTanqueConf = action;
        configChanged = true;
        Serial.printf("Horario: bombaTanqueConf cambiado a %d\n", action);
      }
    }
  }

  if (configChanged) {
    actuadores();
    enviarDatos();
  }
}

// =======================
// SETUP
// =======================
void setup()
{
  Serial.begin(115200);

  wifiConect();
  
  // Inicializar NTP para Argentina (GMT-3)
  configTime(-3 * 3600, 0, "pool.ntp.org", "time.nist.gov");
  
  // Cargar horarios desde Preferences
  cargarSchedules();

  otaConfig();
  mqttConfig();
  serverConfig();

  pinMode(SalidaBz, OUTPUT);
  digitalWrite(SalidaBz, LOW);
  pinMode(bombaPileta, OUTPUT);
  digitalWrite(bombaPileta, LOW);
  pinMode(bombaCisterna, OUTPUT);
  digitalWrite(bombaCisterna, HIGH);
  pinMode(bombaTanque, OUTPUT);
  digitalWrite(bombaTanque, HIGH);
  pinMode(Reflectores, OUTPUT);
  digitalWrite(Reflectores, LOW);
  pinMode(luzPileta, OUTPUT);
  digitalWrite(luzPileta, HIGH);
  pinMode(luzGaleria, OUTPUT);
  digitalWrite(luzGaleria, HIGH);
  pinMode(luzGaleriaBorde, OUTPUT);
  digitalWrite(luzGaleriaBorde, HIGH);
  pinMode(salidaAux1, OUTPUT);
  digitalWrite(salidaAux1, HIGH);
  pinMode(salidaAux2, OUTPUT);
  digitalWrite(salidaAux2, HIGH);

  pinMode(nivelAgua, INPUT_PULLUP);
  pinMode(Touch_MAS, INPUT_PULLUP);
  pinMode(Touch_MENOS, INPUT_PULLUP);
  pinMode(Touch_MENU, INPUT_PULLUP);

  sensoresInit();

  secondTicker.attach(1, cadaSegundo);

  delay(2000);

}

// =======================
// LOOP
// =======================
void loop()
{
  wifiLoop();
  ArduinoOTA.handle();
  handleMqtt();
  server.handleClient();
  
  evaluarHorarios();
  
  leerSensores();
  controlBombaPileta();
  actuadores();

  if (Telemetria)
  {
    enviarDatos();
    Telemetria = false;
  }
}

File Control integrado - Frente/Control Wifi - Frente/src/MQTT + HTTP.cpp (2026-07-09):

#include <Arduino.h>
#include <ESP8266WiFi.h>
#include <ESP8266mDNS.h>
#include <WiFiUdp.h>
#include <ArduinoOTA.h>
#include <PubSubClient.h>
#include <DHT.h>
#include <DHT_U.h>
#include <ArduinoJson.h>
#include <Ticker.h>
#include <ESP8266WebServer.h> // Librería para servidor HTTP
#include <EEPROM.h>
#include <time.h>
#define MQTT_MAX_PACKET_SIZE 1024


// Definición de pines
#define SenTyH 14
#define MovPIR2 13
#define MovPIR1 12
#define SalidaBz 16
#define Reflectores 4
#define Sirena 1
#define LuzVereda 5
#define Camaras 3
int fotoPin = A0;

// Prototipos de funciones
void actuadores();
void enviarDatos();
void saveConfig();

// Definición de variables y constantes --------------------------------------------------------------
int intervalData = 60;                // Intervalo de tiempo[seg] en el que se envían datos
bool Telemetria = false;              // Flag para pedir telemetría completa de todas las variables
const char *ssid = "pocha";
const char *wifiPassword = "Vale07Marce05";
const char *mqttServer = "broker.emqx.io";   //"mqtt.eclipseprojects.io";
const int mqttPort = 1883;
const char *mqttUser = "Marce";        // Reemplaza con tu usuario MQTT
const char *mqttPassword = "Aveni793"; // Reemplaza con tu contraseña MQTT
const char *EspUser = "Marce";         // Usuario para accederal ESP8266
const char *EspPassword = "EspAveni5"; // Contraseña para acceder al ESP8266

int CuentaMov = 0;
int movTime = 7;              // Tiempo [seg] de espera entre la primer detección de movimiento y la segunda
char Luz[25];
bool flagMov = false;
int var = 0;
char datos[40];
int TEMPERATURA = 0;
int HUMEDAD = 0;
int fotoval = 0;
int ValorNoche = 500;         // Valor umbral de luz para determinar si es de día o de noche
int valNocheHist = 500;       // 
int histeresisLuz = 300;
int SirenaConf = 0;           // 0 = Siempre apagada, 1 = Siempre encendida, 2 = Automático
bool sirenaST = false;        // Flag de estado de la sirena
int sirenaTime = 3;           // Tiempo [seg] de encendido de la sirena cuando se detecta movimiento
int movRst = 60;              // Tiempo [seg] de reseteo de mvimientos para activación de sirena
bool CamarasEn = true;        // true = Encendidas, false = Apagadas (para resetearlas), Están conectadas al Normal Cerrado del relé
int ReflectoresConf = 2;      // 0 = Siempre apagados, 1 = Siempre encendidos, 2 = Automático
bool reflectoresST = false;   // Flag de estado de los reflectores
int refTime = 300;            // Tiempo [seg] de encendido de los reflectores cuando se detecta movimiento
int LuzVeredaConf = 0;        // 0 = Siempre apagada, 1 = Siempre encendida, 2 = Automático
bool luzVeredaST = false;     // Flag de estado de las luces de Vereda
bool PIR1En = false;           // flag que habilita el sensor PIR1
bool PIR2En = false;           // flag que habilita el sensor PIR2
int SensorN = 0;              // Identifica que entrada de sensor se activó. 0 = Ninguno, 1 = PIR 1, 2 = PIR 2
volatile int refCount = 0;    // Contador de tiempo de encendido de reflectores
volatile int sirenaCount = 0; // Contador de tiempo de encendido de sirena
volatile int movCount = 0;    // Contador de tiempo entre primer movimiento y segundo
volatile int movRstCount = 0; //Contador de tiempo en que se resetean los movimientos contados
volatile int enviaDataCounter = 0;

Ticker secondTicker;
WiFiClient esp8266Client;
PubSubClient mqttClient(esp8266Client);
DHT dht(SenTyH, DHT11);
ESP8266WebServer server(80); // Inicializa el servidor HTTP en el puerto 80

// --- PERSISTENCIA EEPROM ---
const uint32_t EEPROM_SIGNATURE = 0x55AA7788;

struct ScheduleRule {
  bool active;
  uint8_t hour;
  uint8_t minute;
  uint8_t weekdays;  // Bit 0 = Dom, Bit 1 = Lun, ..., Bit 6 = Sab
  uint8_t target;    // 0: Reflectores, 1: Luz Vereda, 2: Sirena
  uint8_t action;    // 0: Apagado, 1: Encendido, 2: Auto
};

ScheduleRule schedules[8];
int ultimoMinutoEvaluado = -1;

// Retorna true si la hora está sincronizada
bool obtenerHoraLocal(struct tm &infoTiempo) {
  time_t ahora = time(nullptr);
  if (ahora < 1600000000) { // Septiembre 2020 aprox
    return false; // No sincronizado todavía
  }
  localtime_r(&ahora, &infoTiempo);
  return true;
}

struct Config {
  uint32_t signature;
  int SirenaConf;
  int ReflectoresConf;
  int LuzVeredaConf;
  bool CamarasEn;
  int intervalData;
  int movTime;
  int ValorNoche;
  int histeresisLuz;
  int sirenaTime;
  int refTime;
  int movRst;
  bool PIR1En;
  bool PIR2En;
  ScheduleRule schedules[8];
} config;

void loadConfig() {
  EEPROM.begin(sizeof(Config));
  EEPROM.get(0, config);
  if (config.signature != EEPROM_SIGNATURE) {
    // Configuración por defecto si la firma no coincide
    config.signature = EEPROM_SIGNATURE;
    config.SirenaConf = 0;
    config.ReflectoresConf = 2;
    config.LuzVeredaConf = 0;
    config.CamarasEn = true;
    config.intervalData = 60;
    config.movTime = 7;
    config.ValorNoche = 500;
    config.histeresisLuz = 300;
    config.sirenaTime = 3;
    config.refTime = 300;
    config.movRst = 60;
    config.PIR1En = false;
    config.PIR2En = false;
    
    // Inicializar horarios inactivos
    for (int i = 0; i < 8; i++) {
      config.schedules[i].active = false;
      config.schedules[i].hour = 0;
      config.schedules[i].minute = 0;
      config.schedules[i].weekdays = 0;
      config.schedules[i].target = 0;
      config.schedules[i].action = 0;
    }
    
    EEPROM.put(0, config);
    EEPROM.commit();
  }
  
  // Asignar variables globales
  SirenaConf = config.SirenaConf;
  ReflectoresConf = config.ReflectoresConf;
  LuzVeredaConf = config.LuzVeredaConf;
  CamarasEn = config.CamarasEn;
  intervalData = config.intervalData;
  movTime = config.movTime;
  ValorNoche = config.ValorNoche;
  histeresisLuz = config.histeresisLuz;
  sirenaTime = config.sirenaTime;
  refTime = config.refTime;
  movRst = config.movRst;
  PIR1En = config.PIR1En;
  PIR2En = config.PIR2En;
  for (int i = 0; i < 8; i++) {
    schedules[i] = config.schedules[i];
  }
}

void saveConfig() {
  config.SirenaConf = SirenaConf;
  config.ReflectoresConf = ReflectoresConf;
  config.LuzVeredaConf = LuzVeredaConf;
  config.CamarasEn = CamarasEn;
  config.intervalData = intervalData;
  config.movTime = movTime;
  config.ValorNoche = ValorNoche;
  config.histeresisLuz = histeresisLuz;
  config.sirenaTime = sirenaTime;
  config.refTime = refTime;
  config.movRst = movRst;
  config.PIR1En = PIR1En;
  config.PIR2En = PIR2En;
  for (int i = 0; i < 8; i++) {
    config.schedules[i] = schedules[i];
  }
  
  EEPROM.put(0, config);
  EEPROM.commit();
}
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

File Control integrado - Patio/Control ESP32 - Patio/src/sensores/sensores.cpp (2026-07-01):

#include "sensores.h"
#include <DHT.h>
#include <OneWire.h>
#include <DallasTemperature.h>
#include <Preferences.h>

// Timers para lecturas no bloqueantes
unsigned long ultimoDHT = 0;
unsigned long ultimoDS18_Req = 0;
bool ds18_conversionEnProgreso = false;
unsigned long ultimoLuzNivel = 0;

// =====================================================
// OBJETOS DE SENSORES
// =====================================================
DHT dht(SenTyH, DHT22);
OneWire oneWireObj(pinDatoTemp);
DallasTemperature ds18(&oneWireObj);
Preferences prefs;

// =====================================================
// FLAGS DE ESTADO
// =====================================================
bool dhtOK = true;
bool dsOK_pileta = true;
bool dsOK_colector = true;
bool nivelOK = true;
bool luzOK = true;

// =====================================================
// GLOBALES INTERNAS
// =====================================================
DeviceAddress romPileta;
DeviceAddress romColector;
bool romsCargadas = false;
bool nivelAguaST = false;

// =====================================================
// FILTRO
// =====================================================
float filtrar(float valorPrev, float lecturaNueva, float factor = 0.2)
{
    return (valorPrev * (1.0 - factor)) + (lecturaNueva * factor);
}

// =====================================================
// FUNCIONES AUXILIARES ROM
// =====================================================

bool mismaROM(const uint8_t *a, const uint8_t *b)
{
    for (int i = 0; i < 8; i++)
        if (a[i] != b[i]) return false;
    return true;
}

bool validarROMsEnBus()
{
    int cant = ds18.getDeviceCount();
    if (cant != 2) return false;

    DeviceAddress a0, a1;
    ds18.getAddress(a0, 0);
    ds18.getAddress(a1, 1);

    bool piletaOK =
        mismaROM(a0, romPileta) || mismaROM(a1, romPileta);

    bool colectorOK =
        mismaROM(a0, romColector) || mismaROM(a1, romColector);

    return piletaOK && colectorOK;
}

void guardarROMs()
{
    prefs.begin("ds18b20", false);
    prefs.putBool("ready", true);
    prefs.putBytes("pileta", romPileta, 8);
    prefs.putBytes("colector", romColector, 8);
    prefs.end();
}

bool cargarROMs()
{
    prefs.begin("ds18b20", true);

    if (!prefs.getBool("ready", false)) {
        prefs.end();
        return false;    // nunca se guardó nada
    }

    prefs.getBytes("pileta", romPileta, 8);
    prefs.getBytes("colector", romColector, 8);
    prefs.end();
    return true;
}

void guardarIntercambioST()
{
    prefs.begin("config", false);
    prefs.putBool("swap_ds", IntercambioST);
    prefs.end();

    Serial.printf("IntercambioST guardado: %d\n", IntercambioST);
}

void cargarIntercambioST()
{
    prefs.begin("config", true);
    IntercambioST = prefs.getBool("swap_ds", false);
    prefs.end();

    Serial.printf("IntercambioST cargado: %d\n", IntercambioST);
}


// =====================================================
// Registrar sensores por ROM
// =====================================================
void registrarSensores()
{
    ds18.begin();
    int cant = ds18.getDeviceCount();

    Serial.printf("Sensores DS18B20 detectados: %d\n", cant);
    if (cant != 2) {
        Serial.println("ERROR: Deben haber exactamente DOS DS18B20");
        return;
    }

    DeviceAddress a0, a1;
    ds18.getAddress(a0, 0);
    ds18.getAddress(a1, 1);

    // Mantener consistencia siempre igual
    if (memcmp(a0, a1, 8) < 0) {
        memcpy(romPileta, a0, 8);
        memcpy(romColector, a1, 8);
    } else {
        memcpy(romPileta, a1, 8);
        memcpy(romColector, a0, 8);
    }

    guardarROMs();
    Serial.println("ROMs DS18B20 registradas.");
}

// =====================================================
// Inicialización
// =====================================================
void sensoresInit()
{
    cargarIntercambioST();   // 👈 primero esto

    dht.begin();
    ds18.begin();
    ds18.setWaitForConversion(false); // No bloqueante

    if (!cargarROMs()) {
        Serial.println("No hay ROM guardada. Registrando...");
        registrarSensores();
        romsCargadas = true;
    }
    else {
        Serial.println("ROMs DS18B20 cargadas desde memoria.");

        if (!validarROMsEnBus()) {
            Serial.println("ROMs no coinciden. Re-registrando sensores...");
            registrarSensores();
            romsCargadas = true;
        }
        else {
            romsCargadas = true;
        }
    }
}

// =====================================================
// LECTURA SEGURA DS18B20 POR ROM
// =====================================================
void leerDS18()
{
    if (!romsCargadas) return;

    DeviceAddress *romPile;
    DeviceAddress *romCol;

    if (IntercambioST) {
        romPile = &romColector;
        romCol  = &romPileta;
    } else {
        romPile = &romPileta;
        romCol  = &romColector;
    }

    float tPile = ds18.getTempC(*romPile);
    float tCol  = ds18.getTempC(*romCol);

    piletaRaw = ds18.getTempC(romPileta);
    colectorRaw = ds18.getTempC(romColector);

    // === PILETA ===
    if (tPile == DEVICE_DISCONNECTED_C || tPile < -20 || tPile > 80) {
        dsOK_pileta = false;
    } else {
        dsOK_pileta = true;
        tempPileta = filtrar(tempPileta, tPile);
    }

    // === COLECTOR ===
    if (tCol == DEVICE_DISCONNECTED_C || tCol < -20 || tCol > 120) {
        dsOK_colector = false;
    } else {
        dsOK_colector = true;
        tempColector = filtrar(tempColector, tCol);
    }
}

// =====================================================
// LECTURA DHT22
// =====================================================
void leerDHT()
{
    float h = dht.readHumidity();
    float t = dht.readTemperature();

    if (isnan(h) || isnan(t)) {
        dhtOK = false;
        return;
    }

    dhtOK = true;
    HUMEDAD = filtrar(HUMEDAD, h);
    TEMPERATURA = filtrar(TEMPERATURA, t);
}

// =====================================================
// SENSOR NIVEL CAPACITIVO
// =====================================================
void leerNivel()
{
    const int muestras = 10;
    int contadorAgua = 0;

    for (int i = 0; i < muestras; i++)
    {
        if (!digitalRead(nivelAgua))   // LOW = hay agua
            contadorAgua++;

        delayMicroseconds(500);
    }

    // Si más del 70% de las muestras indican agua
    bool nuevoEstado = (contadorAgua > (muestras * 0.7));

    nivelOK = true;

    static bool estadoPrevio = false;
    static uint32_t tCambio = 0;

    if (nuevoEstado != estadoPrevio)
    {
        if (millis() - tCambio >= 100)
        {
            estadoPrevio = nuevoEstado;
            nivelAguaST = nuevoEstado;   // true = hay agua
        }
    }
    else
    {
        tCambio = millis();
    }
}
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

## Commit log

2026-06-27 feat: init commit - version 1.0 estable
    [Base electrónica.stl, Base relés.stl, Carcasa sensor PIR - A.stl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]
2026-06-29 chore(frente): add socket timeout of 1.5s to prevent WDT resets during dead broker connects
    [MQTT + HTTP.cpp]
2026-06-29 feat(app): Agregar aplicacion movil base de Alarma y Domotica. Inicializacion de proyecto Android con Jetpack Compose y Kotlin. Mapeo de estados PatioState/FrenteState, repositorio hibrido MQTT y fal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
2026-07-01 refactor(patio): Eliminar delays bloqueantes, optimizar lectura asincrona de DS18B20/DHT y agregar servidor HTTP local (GET /status, POST /control) para compatibilidad con la App.
2026-07-01 fix(patio): Agregar sufijo .local al puerto de subida OTA para resolucion de nombre mDNS en Windows
2026-07-01 feat: agregar pagina web de control y monitoreo en la ruta raiz del ESP32
2026-07-01 Agrega proyecto Control simple - ESP01 y renombrados de espacio de trabajo
2026-07-02 Corrige tamano maximo de paquete MQTT y simplifica parseador de luz
    [main.cpp]
2026-07-02 Actualiza planos dwg consolidados y agrega gabinete 3D para el modulo ESP01
    [Carcasas.dwg, Central de alarma.dwg, Gabinetes A.stl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]
2026-07-02 Agrega soporte para botones touch en RX y TX para control manual y AUTO del ESP01
2026-07-03 Soporte para modulo ESP-01 en App Movil, actualizacion de planos y nuevo gabinete 3D
    [Gabinetes B.stl, Gabinetes y carcasas.dwg]
2026-07-03 Correcion de pines de reles e inversion de logica para sensores capacitivos en ESP01
    [Gabinetes A.3mf]
2026-07-08 Implementacion de Programacion Horaria y mejoras de robustez en firmware y App
    - Agregada logica autonoma de 8 temporizadores horarios (GMT-3 Argentina) en Patio, Frente y ESP01.
    - Endpoints HTTP y MQTT actualizados para envio/recepcion de JSON con horarios.
    - Anadidos paneles interactivos esteticos para configuracion de horarios en la interfaz web local de cada dispositivo.
    - Optimizados linker scripts (1MB flash sin SPIFFS) en platformio.ini de Frente y ESP01 para corregir fallos OTA de memoria.
    - Agregadas politicas de auto-reconexion WiFi en firmwares ESP8266.
    - Desarrollada la interfaz Compose de Programacion Horaria en la App Android, conectada por HTTP local y MQTT remoto.
    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
2026-07-08 Corregido tamano de buffer JSON en callbacks MQTT de ESP01 y Patio
2026-07-09 Corrige comandos de PIR/Sirena en App y añade actualizacion instantanea de telemetria en firmwares
    [MQTT + HTTP.cpp, SeguridadScreen.kt, conexiones.cpp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]
2026-07-18 Estructura inicial del proyecto Placa Universal ESP32-S3
2026-07-18 Agrega documento inicial de requerimientos de la Placa Universal ESP32-S3
2026-07-18 Agrega documento de recomendaciones de diseño y topología del PCB
2026-07-18 Actualiza requerimientos y diseño del PCB para usar SSRs externos (6 canales)
2026-07-18 Agrega mapa de pinout de referencia para el ESP32-S3 y cabecera C++
2026-07-19 Agrega comparativa de placas y modulos ESP32 para el diseño en Altium
2026-07-19 Reorganiza carpeta Hardware: separa Diseño y Proyecto PCB para Altium
2026-07-19 Agrega seccion de componentes de soporte minimos para ESP32-S3 en PCB
2026-07-19 Agrega lista de control (checklist) para el diseño del PCB
2026-07-20 Agrega guia de conector USB-C y proteccion de energia, mas archivos del proyecto Altium
    [ESP32-S3-WROOM-1-N8R8.STEP, ESP32.SchDoc, Placa Universal - ESP32.PrjPcb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]
2026-07-21 Agrega seccion de conexion e integrado de proteccion ESD USBLC6-2SC6
